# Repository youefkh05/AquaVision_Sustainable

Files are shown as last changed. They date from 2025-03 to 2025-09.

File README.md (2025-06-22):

# Lake Sensing Project

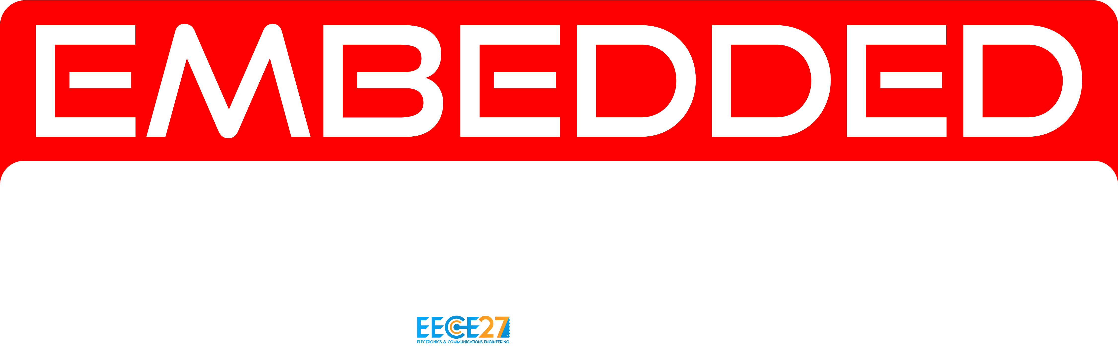
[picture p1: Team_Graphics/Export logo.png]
TEAM Logo Main


>[!IMPORTANT]
> This project is done as part of the Embedded Systems course [ELC2080] taught to second year Electronics and Elecrtic Communication Engineering Students at Cairo University Under the Supervision of Dr. Mohamed Riad.

### **[Dashboard Link](https://amirsameh1.github.io/test/)** To monitor project Data in real-time

## Brief Description

The system employs a dual-microcontroller setup to monitor and transmit water level data at two locations in a lake. The first module, positioned at the center where GSM signal is unavailable, measures water level and temperature, then relays the data via the ESP-NOW protocol to a second module stationed at the lake’s edge. This second unit consolidates the readings and transmits them to a base station using both GSM and Wi-Fi for broader connectivity.

## Project Features:

- Real Time Water-Level and temprature updates
- Accurate Data Measurments using different sensors
- Tracking measurements at two different locations
- Intiutive dashboard displaying data
- GSM connectivity
- Creative UI on Oled inspired by the Flipper Zero UI
- Alarm system if the Water Level is under a specified Limit

## Technical Highlights:

- Uses ESP32 Microcontroller for its wireless capability
- ESP-NOW Protocol used for communication between the two nodes
- GSM Connectivity Sends data to the dashboard in Real-Time.
- Overcoming GSM Challenges using an SMS system.
- Custom designed PCB for Each Node
    - Double Layer for Middle Node
    - Single Layer for Edge Node
- Power Supply filtering circuit to ensure safe operation of all components used
- Measuring water levels using two different methods
    - Ultrasonic Sensor
    - Time of Flight (ToF) Sensor
- Firbase used for storing and collecting data

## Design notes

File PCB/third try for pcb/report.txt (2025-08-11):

Plotted to 'C:\Users\Ziad\Desktop\sch\third try for pcb\gerber files\test-F_Cu.gbr'.
Plotted to 'C:\Users\Ziad\Desktop\sch\third try for pcb\gerber files\test-B_Cu.gbr'.
Plotted to 'C:\Users\Ziad\Desktop\sch\third try for pcb\gerber files\test-F_Paste.gbr'.
Plotted to 'C:\Users\Ziad\Desktop\sch\third try for pcb\gerber files\test-B_Paste.gbr'.
Plotted to 'C:\Users\Ziad\Desktop\sch\third try for pcb\gerber files\test-F_Silkscreen.gbr'.
Plotted to 'C:\Users\Ziad\Desktop\sch\third try for pcb\gerber files\test-B_Silkscreen.gbr'.
Plotted to 'C:\Users\Ziad\Desktop\sch\third try for pcb\gerber files\test-F_Mask.gbr'.
Plotted to 'C:\Users\Ziad\Desktop\sch\third try for pcb\gerber files\test-B_Mask.gbr'.
Plotted to 'C:\Users\Ziad\Desktop\sch\third try for pcb\gerber files\test-Edge_Cuts.gbr'.
Created Gerber job file 'C:\Users\Ziad\Desktop\sch\third try for pcb\gerber files\test-job.gbrjob'.
Info: Done.

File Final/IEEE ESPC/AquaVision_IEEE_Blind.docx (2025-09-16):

Implementation of an IoT-Based Sensor Network with AI Optimization for Aquaculture Systems

Abstract—This research introduces AquaVision, a smart aquaculture prototype integrating Internet of Things (IoT) and cloud technologies to improve fish farming in Egypt. The system continuously monitors key water parameters and automates corrective actions, reducing manual labor and errors. Real-time data analysis provides actionable insights for fish health and farm productivity. Experimental results confirm that AquaVision improves environmental stability and resource utilization. The prototype highlights a pathway toward sustainable, technology-driven aquaculture for food security and economic growth.

Keywords— IoT, aquaculture, smart farming, real-time monitoring, adaptive control, sustainable fish farming.

# I. Introduction

Egyptian aquaculture operations encounter major obstacles when handling water quality while optimizing resources and maintaining environmental equilibrium. Internet of Things technology enables fish farmers to solve their challenges through innovative solutions which transform traditional aquaculture operations. The research examines how IoT technology can be applied to Egyptian aquaculture through the development of AquaVision a prototype system which improves fish farm operations by providing automated monitoring capabilities.[1]

Recent studies show that IoT technology has great potential to enhance small-scale aquaponics systems through aquaculture automation. The combination of IoT technology enables reduced manual labor together with resource optimization and detailed water quality monitoring to create optimal conditions for fish and plants. Small-scale aquaculture operators encounter difficulties because they lack expertise in water chemistry and system maintenance while facing financial obstacles from expensive operational costs and power-hungry equipment.[1]

## A. CHALLANGES IN EGYPT’S AQUACULTURE SECTOR

The Egyptian aquaculture sector functions as an essential component of national food security together with economic development. Fish farmers face multiple problems because of water contamination together with inefficient resource management and environmental problems that stem from climate change. Traditional methods of aquaculture depend entirely on human monitoring which both requires extensive labor and results in frequent errors. The increasing prices of energy together with feed costs create significant financial pressure on fish farms that operate at small and medium scales.[1]

The proper maintenance of water conditions stands as a primary concern in aquaculture because temperature and pH level variations and dissolved oxygen changes result in decreased fish growth as well as increased death rates. Improper disposal of fish waste along with excess feed creates water pollution that affects both the farm site and nearby aquatic ecosystems as shown in fig 1[3]. The solution to these problems requires an automated system which can perform continuous monitoring and control of essential parameters.

Fig. 1. Challenges in aquaculture systems.

## B. The Role of IoT and AI in Smart Aquaculture

The Internet of Things technology offers fish farmers a solution to their operational challenges which includes water quality management and resource optimization and environmental sustainability through its integration into aquaculture operations. IoT-based systems enable real-time data collection and automated responses to environmental changes, as demonstrated in Fig 2. Smart feeders along with water quality sensors and automated aeration systems operate to maintain optimal conditions which eliminates the need for constant human monitoring.[2]

Fig. 2. Smart Aquaculture System.

# II. LITERATURE REVIEW

The implementation of IoT technology within aquaculture represents a forward-looking solution which addresses the problems of fish farmers especially in developing nations such as Egypt. Research demonstrates that implementing IoT-based systems within fish farms generates better productivity together with scalability and sustainability. According to a systematic review[2] IoT shows great potential to enhance both operational efficiency and financial returns in small-scale aquaponics systems which combine fish farming with hydroponics. The authors highlight IoT's vital role in resource optimization and constant water quality tracking and maintaining ideal conditions for fish and plant growth. Research has proven that smart monitoring and management systems based on IoT deliver improved business development alongside increased productivity to fish farming operations which utilize next-generation technologies.

## A. IoT in Aquaculture: Enhancing Monitoring and Environmental Control

The achievement of aquaculture systems depends heavily on maintaining high water quality. Multiple research investigations have proven that IoT-based monitoring provides benefits for maximizing environmental condition optimization.

- A systematic review shows how IoT brings value to small-scale aquaponics through resource optimization and detailed water quality monitoring of pH and dissolved oxygen and temperature and ammonia levels.[3]
- The research "Enhancing Tilapia Fish Farming Through IoT-driven Monitoring and Automatic Feeding Technology" presents real-time data collection evidence which demonstrates automated monitoring produces enhanced fish growth rates and better farm efficiency through cloud-based analytics.[4]

These Research shows that IoT technology-based real-time monitoring helps fish farmers achieve optimal conditions while lowering environmental threats and reducing the number of fish deaths.

## B. Automation in Fish Farming: Smart Feeding and Resource Optimization

Automated feeding systems function as a fundamental element for IoT-based fish farming operations because they solve problems caused by manual feeding processes.

- The "Improving Fish Quality and Yield: An Automated Monitoring System for Intensive Aquaculture." presents an IoT-based feeding solution which maximizes feeding times to prevent excessive feeding and feed loss.[6]
- The "Design of Automated Fish Feeder Using IoT" highlights how adjustable feeding patterns together with remote management and optimized portions lead to better fish health outcomes and higher farm efficiency.[7]

These Research shows that automated feed management based on IoT technology delivers higher operational efficiency together with decreased human mistakes and reduced operational expenses in fish farming operations.

## C. IoT-Driven Management Strategies and Business Development

The Internet of Things (IoT) technology assists farm operators by enhancing their ability to make decisions and manage their operations together with its monitoring and feeding capabilities.

- The “IoT-Based Smart Monitoring and Management System for Fish Farming,” describes how computer and communication technology enables operators to remotely supervise and control their fish farms.[8]
- A case study at the University of Rwanda Fish Farming and Research Station (UR-FFRs) shows that real-time alerts combined with cloud computing improve data analysis and decision-making through IoT implementation.[9].

These studies indicate that IoT implementation stands as a transformative force for aquaculture because it allows precise farming methods and boosts productivity and promotes sustainable business growth.

## D. Summary of Literature Findings

The examined studies reveal these crucial points which represent the main findings:

1. The use of real-time environmental parameter monitoring enables fish mortality reduction alongside improved resource utilization. Automated feeding systems enhance operational efficiency by stopping excess feeding which lowers feed waste and supports better fish development. IoT-based management approaches lead to improved decision-making and lower operational expenses and advance sustainable aquaculture operations.
2. The collected knowledge forms an essential base for creating AquaVision which will function as a smart aquaculture prototype to connect IoT systems for improved fish farm efficiency through automated operations and immediate monitoring.

# III. METHODOLOGY

## A. Sensor Data Collection

Our monitoring system employs multiple sensors for water quality and environmental conditions detection in aquaculture systems which track essential parameters. These parameters include:

- Water Level measures available water quantity for fish survival together with optimal growth conditions.
- The pH Level system tracks aquatic acidity levels which directly influences fish metabolic processes and their wellness.
- The temperature value (Temp) directly influences fish growth speed together with metabolic processes and dissolved oxygen capacity. Our system defines T &gt; 32°C as an initial critical threshold for temperature measurement.
- The dissolved oxygen level (DO) is necessary for aquatic life respiration and total water health with DO 8 mg/L as its standard critical threshold.
- Sunlight intensity determines the rate of photosynthesis among aquatic plants and algae which subsequently modifies oxygen production and nutrient cycling.

## B. System Components in Egyptian Fish Farms

The proposed system combines multiple essential elements to optimize fish farming operations in Egypt as shown in fig 3[2]. The aquatic tanks function as the main habitat for cultured fish while the water filtration system operates to preserve water quality through removal of debris and oxygen level management. The pipeline system enables water to move efficiently between fish tanks and filtration units. The system integrates plant cultivation to enable aquaponic practices which use fish waste as a natural fertilizer for plant growth. The system controls lighting to support both fish and plant growth and uses a water pump to control fluid movement and maintain system stability. The system achieves sustainable fish farming through the integrated operation of its components.

Fig. 3. The Overall Aquaponic System

## C. Prototype Development

The proposed system combines multiple essential elements to optimize fish farming operations in Egypt as shown in fig 4

Fig. 4. Prototype PCB with ESP32

The aquatic tanks function as the main habitat for cultured fish while the water filtration system operates to preserve water quality through removal of debris and oxygen level management. The pipeline system enables water to move efficiently between fish tanks and filtration units. The system integrates plant cultivation to enable aquaponic practices which use fish waste as a natural fertilizer for plant growth. The system controls lighting to support both fish and plant growth and uses a water pump to control fluid movement and maintain system stability. The system achieves sustainable fish farming through the integrated operation of its components.

For real-time control and monitoring of this process, two ESP32 microcontrollers are utilized. The first ESP32 is utilized for sensor parameter detection data acquisition such as water temperature, pH, and oxygen level. The second ESP32 is utilized for control and communication such as data uploading to a cloud server and downloading a remote smart phone application control command. This setup of two microcontrollers allows for real-time remote control and secure data acquisition, which permits users to make the correct decision and act on any irregularity in the aquaculture condition in real time.[10]

1) Algorithm for System Monitoring: The system employs a pre-programmed algorithm which takes sensor readings as an input and triggers the required action based on pre-programmed threshold values. The algorithm keeps on monitoring real-time sensor readings and makes required modifications to the control system.[2]

The algorithm operates as follows:

1. Read Sensor Data – It takes input from temperature, pH, DO, water level, and sunlight sensors.
2. Threshold Comparison – Compares values rising or falling below set thresholds (e.g, Temp > 32°C, DO > 8 mg/L).
3. Triggers Control Actions – Upon a parameter reaching its critical value, control actions such as the start of operation of aerators, water pumps, or shading systems are initiated.
4. Data Log and Alert System – Stores all the readings to be analyzed and sends alerts in the event of anomalies.

## D. Adaptive AI-Based Optimization

We use basic threshold-based control systems, but our extension introduces an AI-based adaptive control to dynamically adjust threshold levels based on environment conditions and trend histories. It operates as follows:

- The AI model analyzes past sensor readings for correlations and trends.
- Instead of using constant limits (e.g., Temp > 32°C, DO > 8 mg/L), the AI adjusts them based on external inputs such as weather outlooks, phases of fish growth, and seasons.
- This optimization maximizes water quality, reduces energy consumption, and improves fish health by keeping the parameters within an optimal range rather than fixed pre-set values.

# IV. EXPERIMENTAL RESULTS

The AquaVision prototype was evaluated under small-scale aquarium conditions due to limitations in accessing a commercial fish farm. Despite this constraint, the setup provided a controlled environment to validate the system’s functionality in monitoring water parameters such as temperature and water level.[10]

As shown in fig 5, The AquaVision prototype was evaluated under small-scale aquarium conditions due to limitations in accessing a commercial fish farm. Despite this constraint, the setup provided a controlled environment to validate the system’s functionality in monitoring water parameters such as temperature and water level.[10]

Previous studies report that manual monitoring in aquaculture achieves only around 30% accuracy in maintaining optimal water parameters due to delays, inconsistency, and human error [6]. In contrast, our prototype, although still at an early stage, achieved an accuracy of approximately 40% when compared against calibrated sensors and expected threshold behavior.

While this result indicates that AquaVision has not yet reached its full potential, it demonstrates a clear improvement over traditional manual methods. The accuracy is expected to increase significantly as the AI-based adaptive control algorithm is further trained and optimized with more environmental data from larger-scale fish farm deployments.

Fig. 5. Manual vs our AI prototype accuracy

# V. CONCLUSION

Application of IoT technology to Egypt's aquaculture industry is a new idea of water quality management, being environment conserving, and an environmental guardian. The process here demonstrates the worth of real-time monitoring, automated control, and machine learning analysis in fish farm productivity, enhancement of fish health, and cost reduction. The AquaVision demonstrator demonstrates the potential for sensor networks and cloud computing to work towards delivering data-driven decision-making, ideal farming conditions with maximum possible resource utilization.

Despite advancements, large application of IoT in aquaculture is constrained by the demands of start-up capital-expenditure investment, cyberattacks, and technical expertise. It will increase use of the technology in solving the above challenges through cost-saving methods, enhanced security mechanisms, and farmers' capacity building. Egypt's aquaculture fishery sector can increase productivity, sustainability, and profitability through the utilization of IoT, the path to a robust and evidence-based aquaculture

##### References

[1] M. A. H. bin Zamnuri, S. Qiu, M. A. A. bin Rizalmy, W. He, S. Yusoff, K. A. Roeroe, J. Du, and K.-H. Loh, “Integration of IoT in small-scale aquaponics to enhance efficiency and profitability: A systematic review,” Animals, vol. 14, no. 17, p. 2555, 2024.
[2] M. M. M. Mahmoud, R. Darwish, and A. M. Bassiuny, “Development of an economic smart aquaponic system based on IoT,” J. Eng. Res., vol. 12, no. 4, pp. 886–894, 2024.
[3] R. Basso-Sartori, “Current status of the microalgae application in agriculture and aquaculture,” unpublished, accessed Mar. 22, 2025.
[4] D. N. Purnamasari, I. R. Dhani, D. T. Laksono, M. Ulum, M. Hardiwansyah, and R. Alfita, “Enhancing tilapia fish farming through IoT-driven monitoring and automatic feeding technology,” in Proc. IEEE Int. Conf. Inf. Technol. Inf. Syst. (ITIS), Oct. 2023.
[5] M. Karim, M. Rahman, S. Alam, and T. Hasan, “IoT-based smart fish farming aquaculture monitoring system,” Apr. 2021.
[6] A. D. Kannan, R. Sivakumar, and P. Subramani, “Improving fish quality and yield: An automated monitoring system for intensive aquaculture,” Malays. J. Sci. Adv. Technol., 2024.
[7] P. Gade, M. Vaidya, D. Jaiswal, A. Titarmare, and R. Bambodkar, “Design of automated fish feeder using IoT,” Int. J. Res. Appl. Sci. Eng. Technol., vol. 11, no. 6, pp. 715–718, 2023.
[8] M. I. H. Bhuiyan, T. T. Mishuk, M. M. Islam, and M. S. Hossain, “IoT-based smart monitoring and management system for fish farming,” Bull. Electr. Eng. Informatics, vol. 11, no. 6, pp. 3183–3191, Dec. 2022. [Online].Available: https://journal.beei.org/index.php/EEI/article/view/3365
[9] M. I. H. Bhuiyan, T. T. Mishuk, M. M. Islam, and M. S. Hossain, “IoT-based smart monitoring and management system for fish farming,” Bull. Electr. Eng. Informatics, vol. 11, no. 6, pp. 3183–3191, Dec. 2022. [Online].Available: https://journal.beei.org/index.php/EEI/article/view/3365
[10] “AquaVision Sustainable,” GitHub repository, 2025. [Online].Available: https://tinyurl.com/3f9ve6mb

XXX-X-XXXX-XXXX-X/XX/$XX.00 ©20XX IEEE

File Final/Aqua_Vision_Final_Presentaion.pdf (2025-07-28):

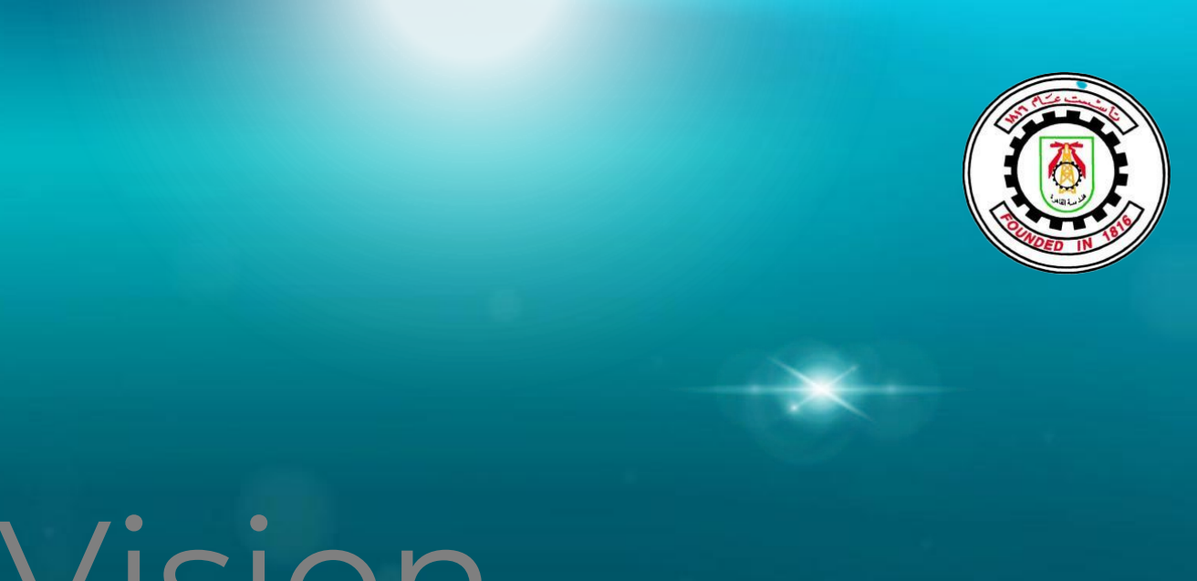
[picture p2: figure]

# Aqua Vision

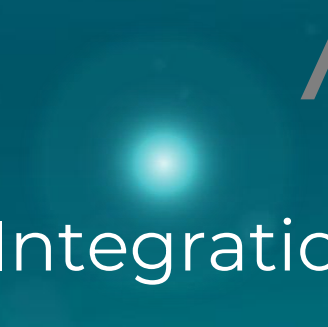
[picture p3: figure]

## Integration of IoT Technology with AI in Egypt's Aquaculture Industry

### Supervision: Dr. Samah El-Shafiey

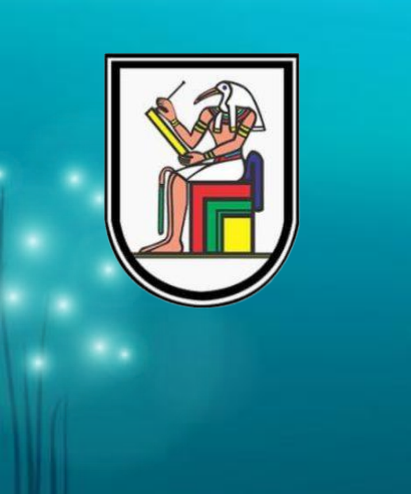
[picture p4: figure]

### Presented by: Yousef Khaled | Ameer Louly | Mohamed Ahmed

1

# TABLE OF CONTENTS

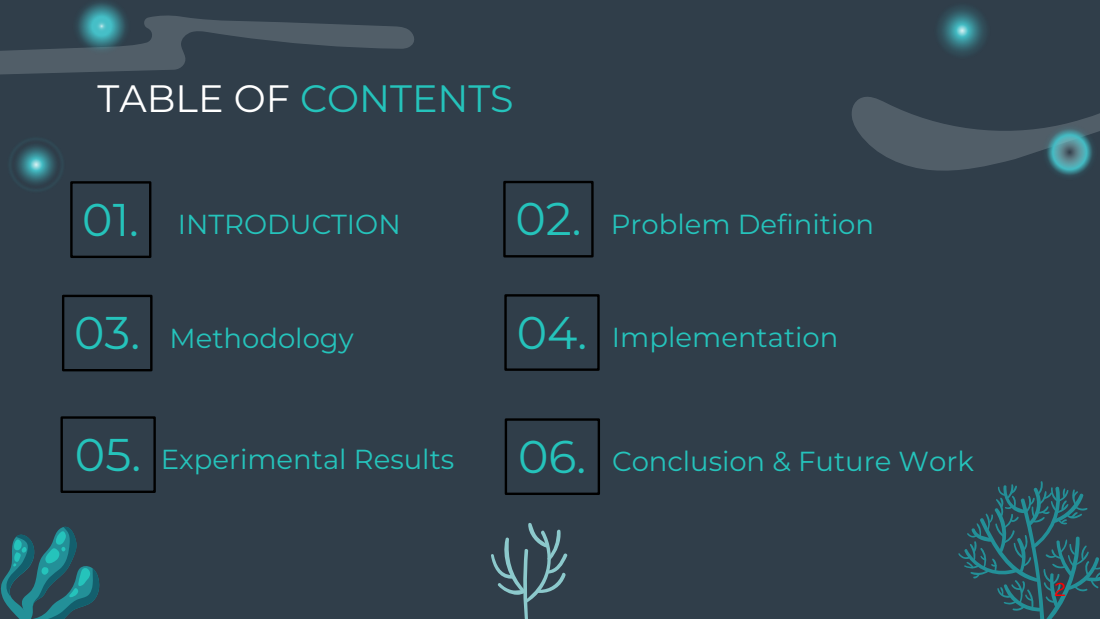
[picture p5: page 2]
INTRODUCTION; Problem Definition; Methodology; Implementation; Experimental Results; Conclusion & Future Work

# INTRODUCTION

01.

# 01. INTRODUCTION

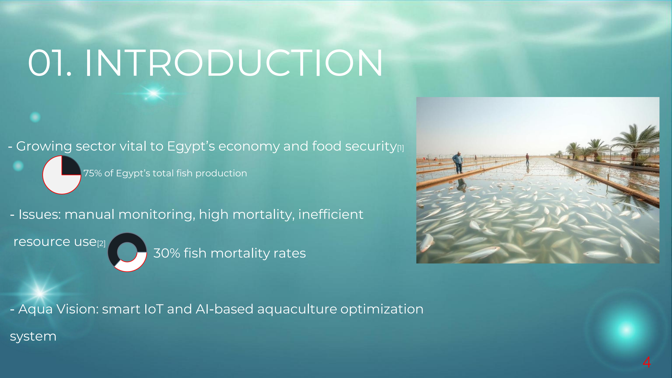
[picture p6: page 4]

- Growing sector vital to Egypt’s economy and food security[1]
- Issues: manual monitoring, high mortality, inefficient resource use[2]
- Aqua Vision: smart IoT and AI-based aquaculture optimization system

75% of Egypt’s total fish production

30% fish mortality rates

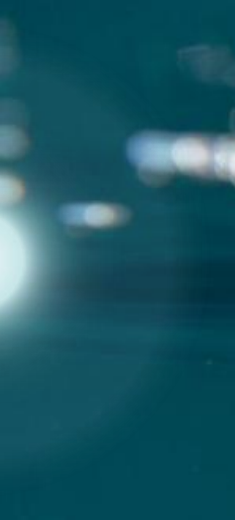
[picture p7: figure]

# Problem Definition

02.

# 02.Problem Definition

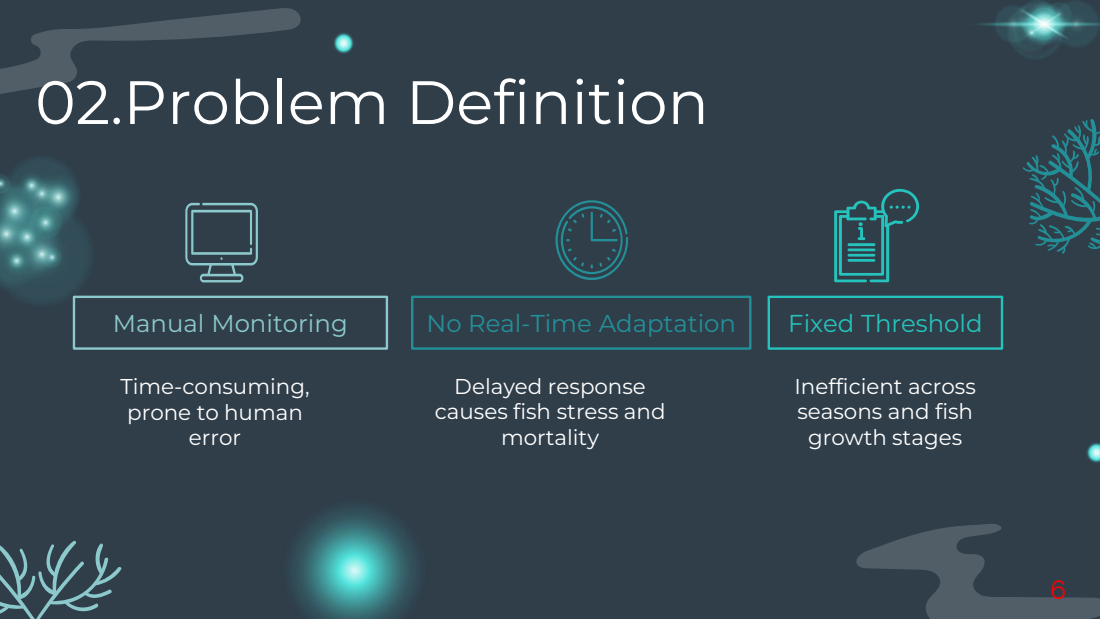
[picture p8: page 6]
Manual Monitoring; No Real-Time Adaptation; Fixed Threshold

Delayed response
causes fish stress and
mortality

Inefficient across
seasons and fish
growth stages

Time-consuming,
prone to human
error

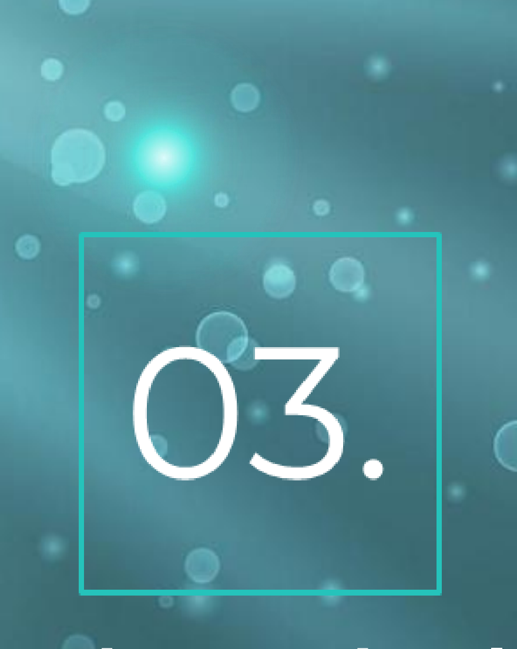
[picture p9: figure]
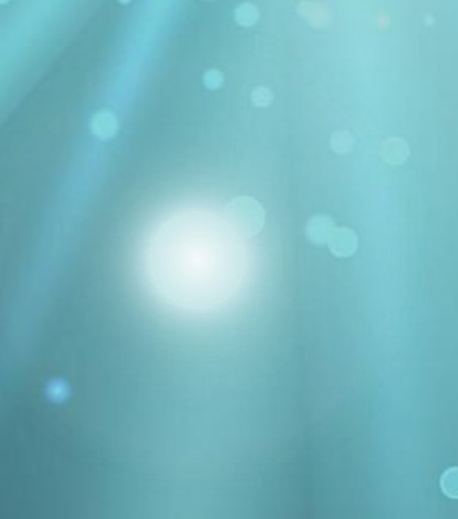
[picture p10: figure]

# Methodology

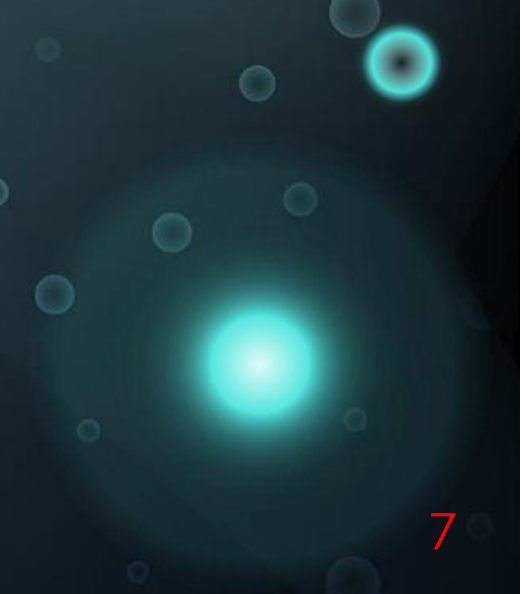
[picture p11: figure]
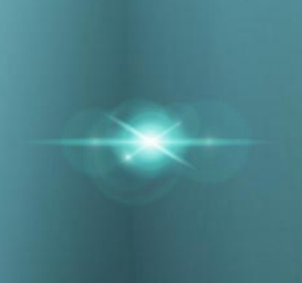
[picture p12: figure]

# Methodology

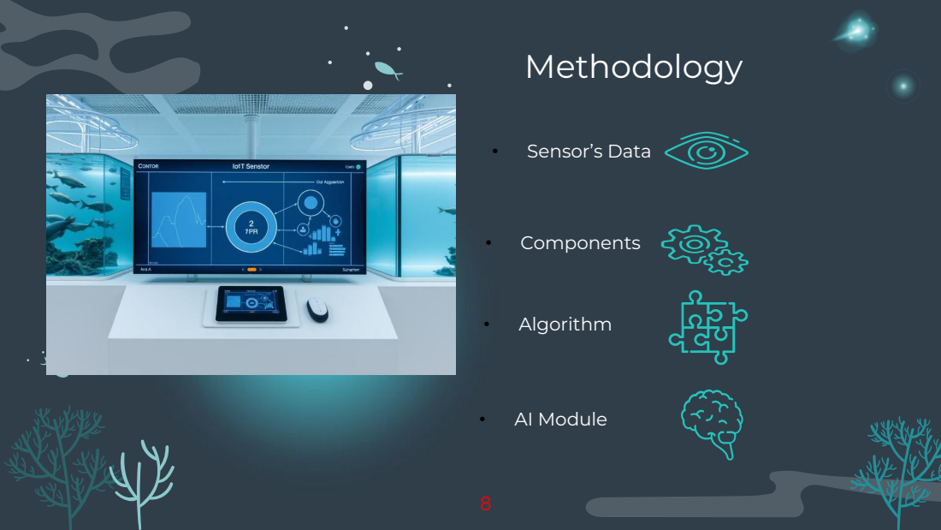
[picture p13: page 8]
• Sensor’s Data; • Components; • Algorithm; • AI Module

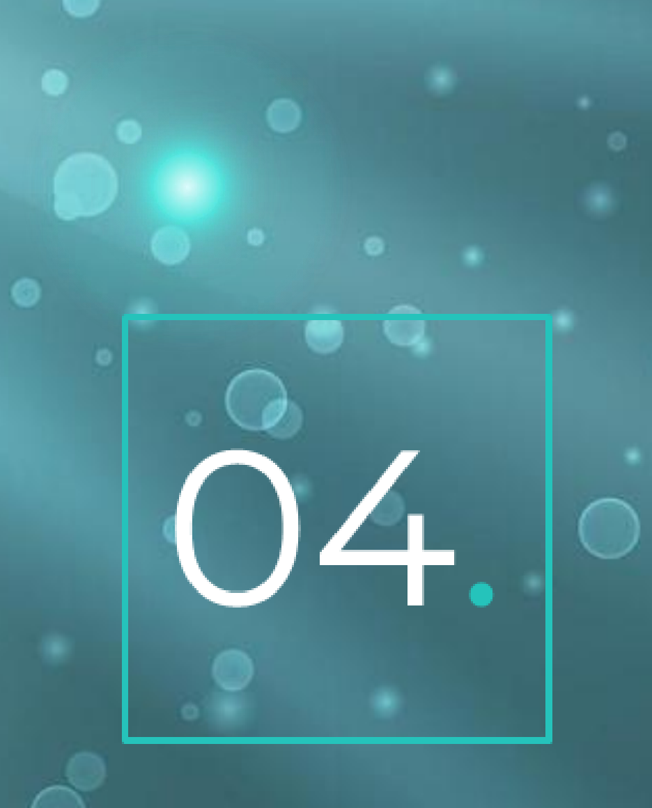
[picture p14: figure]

# Implementation

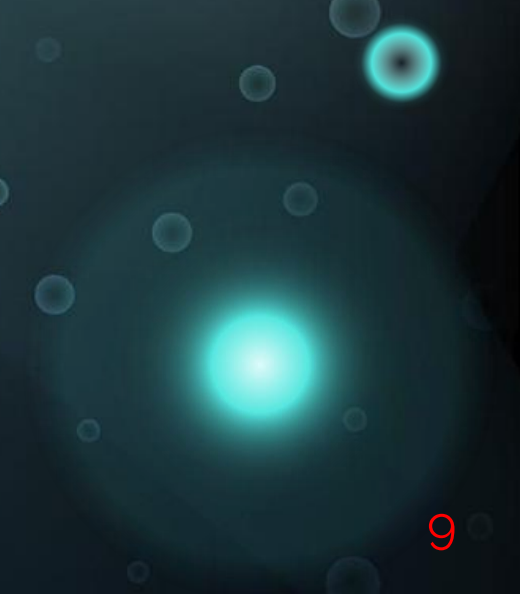
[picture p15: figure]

# Implementation

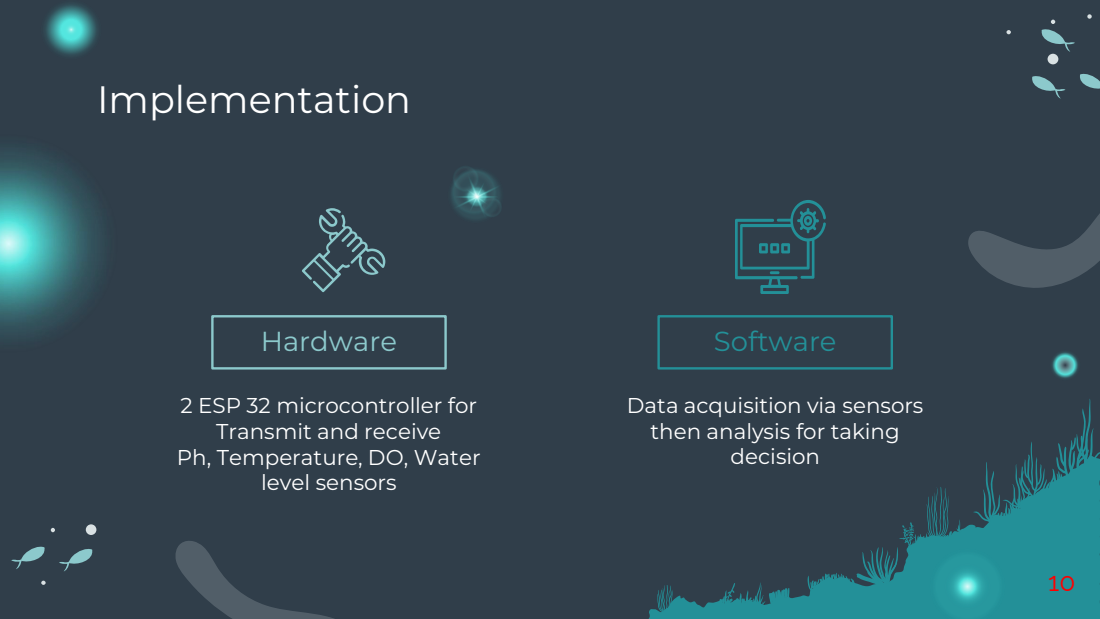
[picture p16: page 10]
Hardware; Software; level sensors; decision

2 ESP 32 microcontroller for
Transmit and receive
Ph, Temperature, DO, Water

Data acquisition via sensors
then analysis for taking

# Algorithm

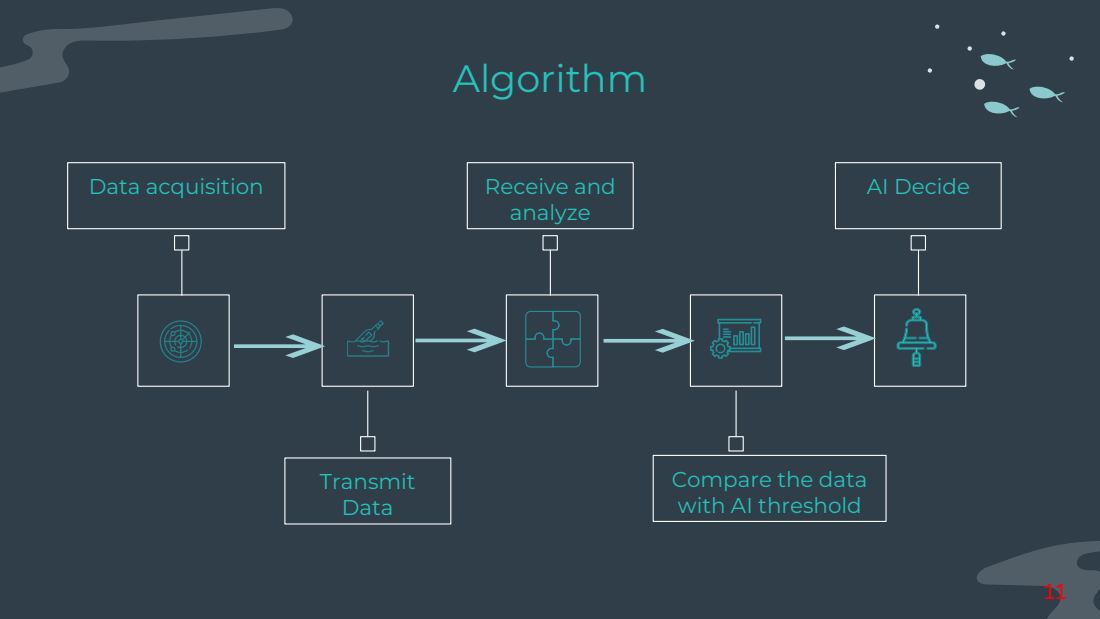
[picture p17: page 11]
Data acquisition; Receive and; analyze; AI Decide; Transmit Data

Compare the data
with AI threshold

# Experimental Results 5

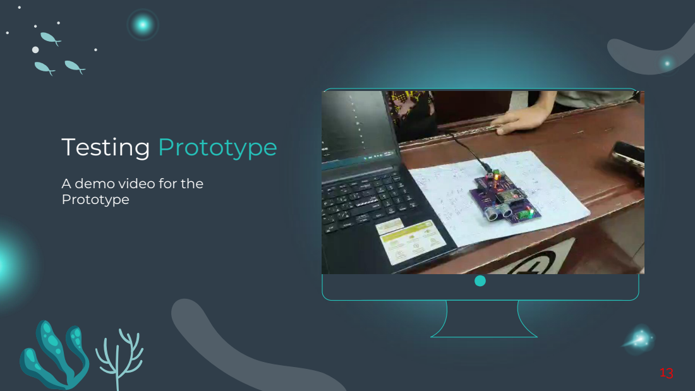
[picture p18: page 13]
Testing Prototype

A demo video for the
Prototype

# Key Results

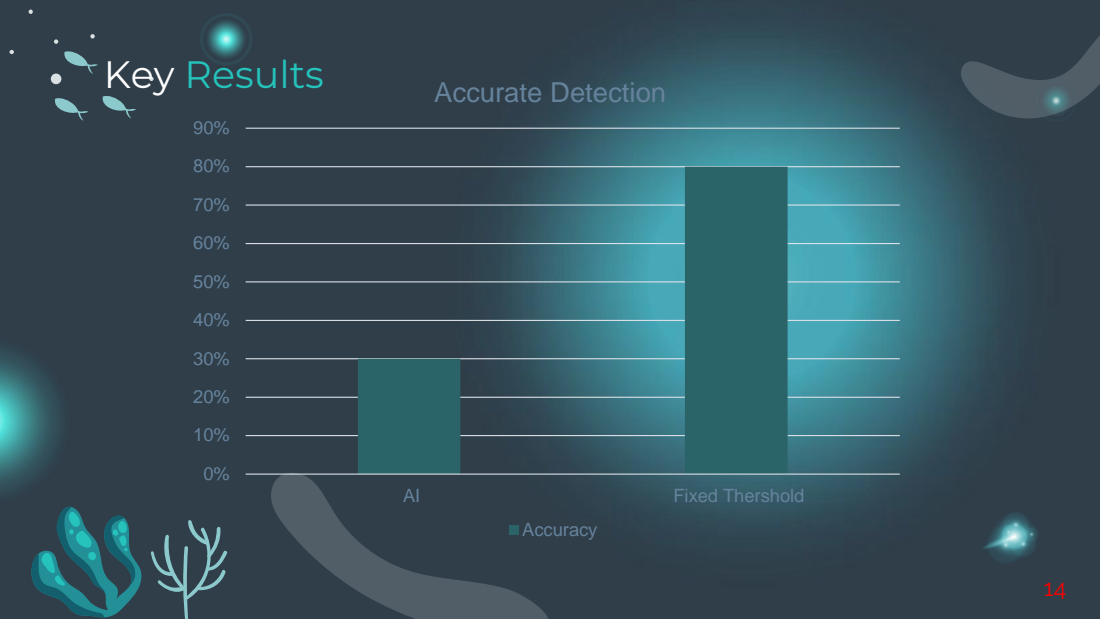
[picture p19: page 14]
Fixed Thershold; Accurate Detection; Accuracy

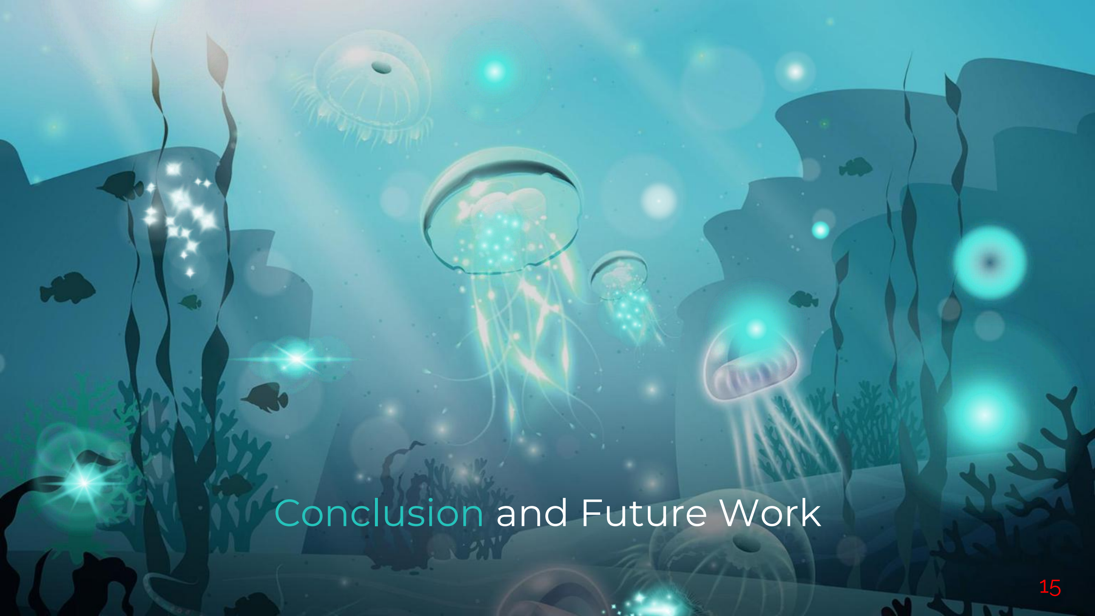
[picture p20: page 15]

# Conclusion and Future Work

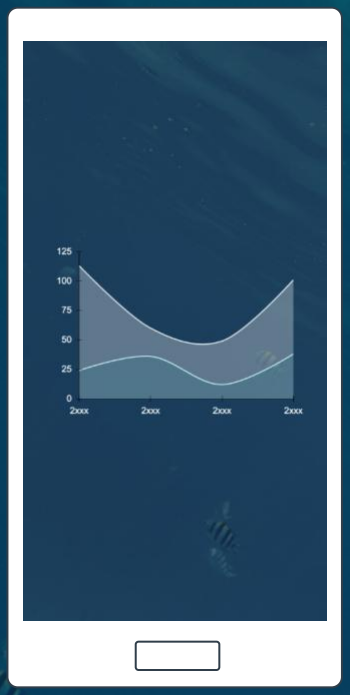
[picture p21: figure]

# Conclusion

- IoT and AI integration boosts smart aquaculture
- Enhances monitoring, cost efficiency, sustainability

## Cloud and mobile remote management

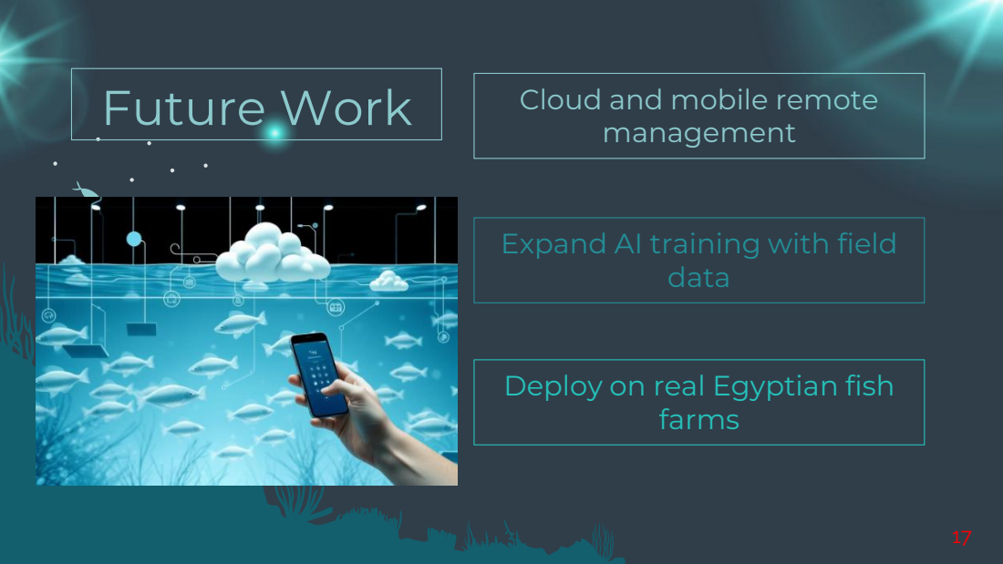
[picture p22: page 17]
data; farms; Future Work

Expand AI training with field

Deploy on real Egyptian fish

# THANKS!

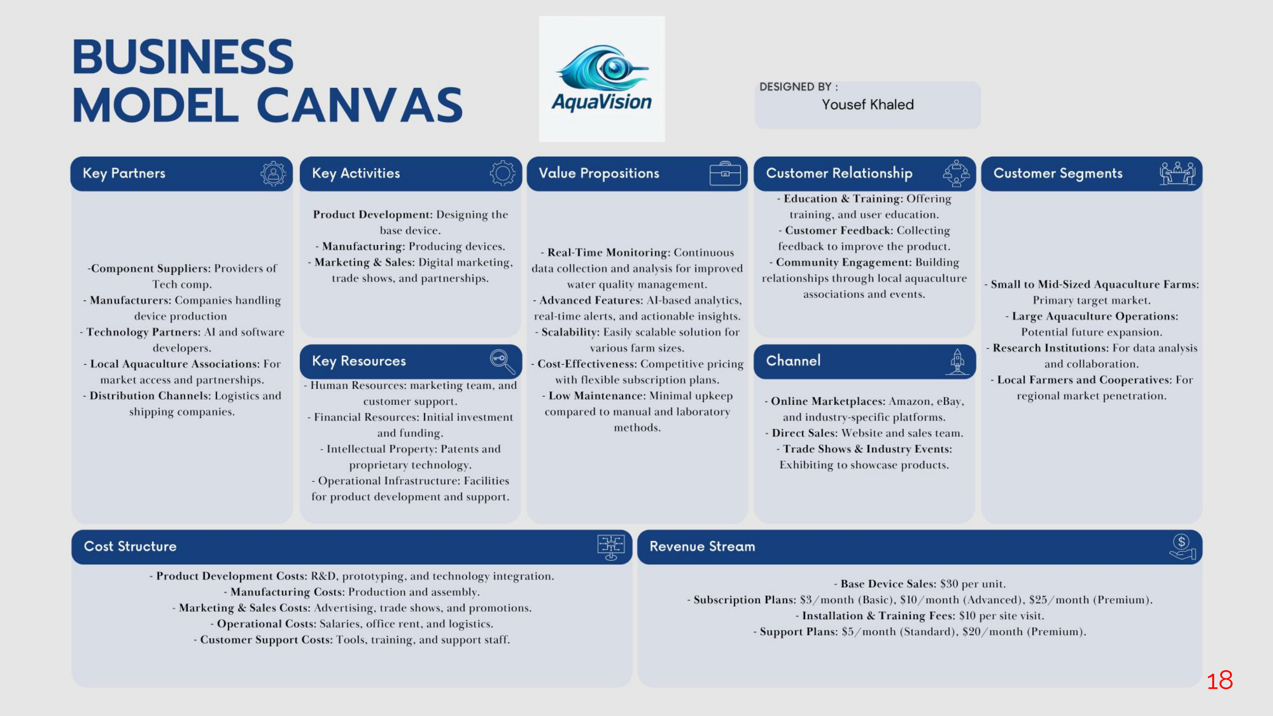
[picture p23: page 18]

CREDITS: This presentation template was created by Slidesgo, (http://bit.ly/2Tynxth) and includes icons by Flaticon, (http://bit.ly/2TyoMsr) and infographics & images by Freepik (http://bit.ly/2TtBDfr)

# Do you have any questions?

CREDITS: This presentation template was created by Slidesgo, (http://bit.ly/2Tynxth) and includes icons by Flaticon, (http://bit.ly/2TyoMsr) and infographics & images by Freepik (http://bit.ly/2TtBDfr)

# THANKS!

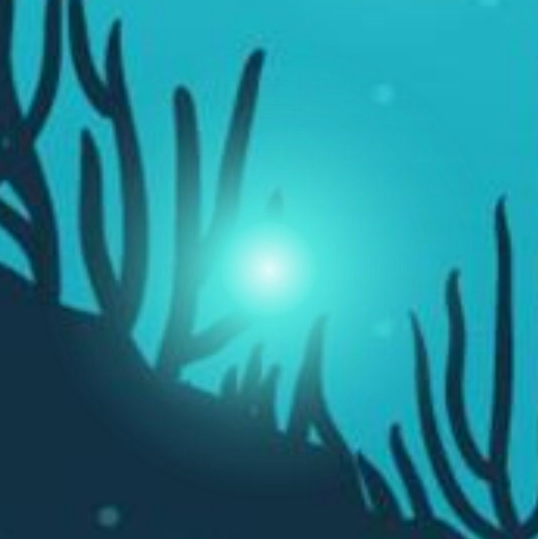
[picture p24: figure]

# Do you have any questions?

# QR Code

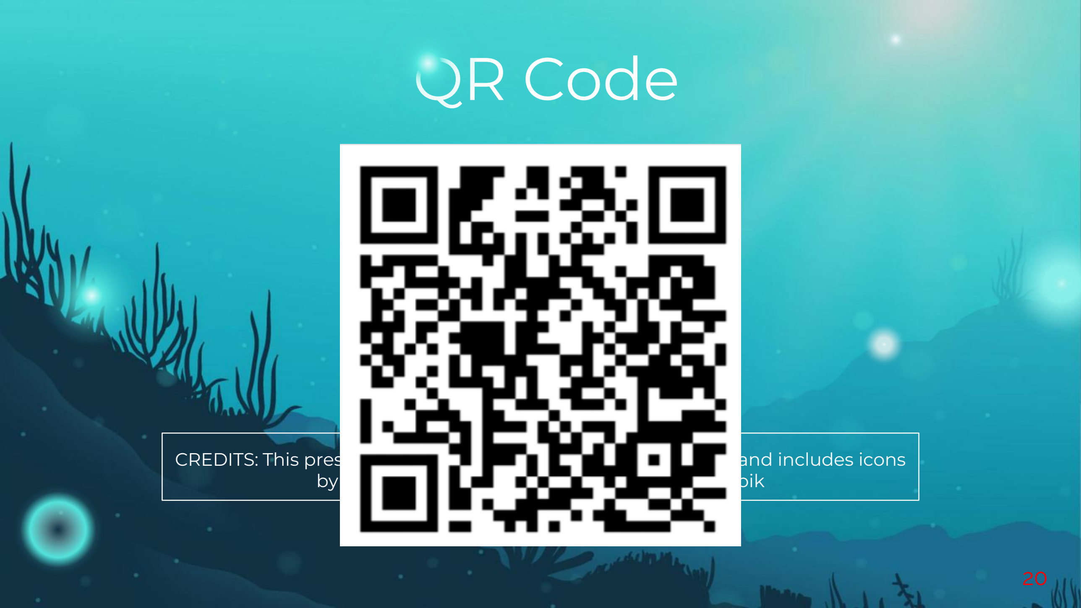
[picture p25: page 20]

CREDITS: This presentation template was created by Slidesgo, (http://bit.ly/2Tynxth) and includes icons by Flaticon, (http://bit.ly/2TyoMsr) and infographics & images by Freepik (http://bit.ly/2TtBDfr)

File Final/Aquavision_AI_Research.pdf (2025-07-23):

Cairo University

### | P a g e 1

## Integration of IoT Technology with AI in Egypt's Aquaculture Industry: AquaVision Prototype for Sustainable Fish Farming

Yousef Khaled Omar Mahmoud, Engineering, E-mail: yousef.mahmoud03@eng-st.cu.edu.eg

Gamaa Street, Giza, Egypt

Abstract

The aquaculture sector of Egypt encounters difficulties in managing water quality while optimizing resources and achieving sustainable operations. The research presents AquaVision which serves as an Internet of Things (IoT) based prototype to boost fish farm operational efficiency. The AquaVision system operates through real-time sensor data measurement which enables precise water parameter control that enhances fish growth while minimizing resource consumption. The system provides remote monitoring capabilities and control functions that help users make informed decisions and data analytics tools that generate valuable insights about farm productivity. the innovative system tackles fundamental issues while advancing sustainable aquaculture operations that operate in Egypt.

### 1 INTRODUCTION

Egyptian aquaculture operations encounter major obstacles when handling water quality while optimizing resources and maintaining environmental equilibrium. Internet of Things technology enables fish farmers to solve their challenges through innovative solutions which transform traditional aquaculture operations. The research examines how IoT technology can be applied to Egyptian aquaculture through the development of AquaVision a prototype system which improves fish farm operations by providing automated monitoring capabilities.[1]

Recent studies show that IoT technology has great potential to enhance small-scale aquaponics systems through aquaculture automation. The combination of IoT technology enables reduced manual labor together with resource optimization and detailed water quality monitoring to create optimal conditions for fish and plants. Small-scale aquaculture operators encounter difficulties because they lack expertise in water chemistry and system maintenance while facing financial obstacles from expensive operational costs and power-hungry equipment.[1]

The AquaVision prototype aims to address these challenges by leveraging IoT technology to automate and optimize various aspects of fish farming. The system incorporates real-time sensors to monitor water quality parameters, such as pH, dissolved oxygen, and temperature, and uses this data to adjust water circulation, aeration, and feeding schedules. This not only ensures optimal growing conditions for the fish but also helps to minimize water and energy consumption, thereby enhancing the environmental sustainability of the operation.

AquaVision combines IoT technology to give fish farm owners the capability to track and operate their operations from anywhere which helps them base their decisions on data and react to environmental changes. Through its analytics features the system delivers essential information about fish development patterns together with feeding behaviors and farm productivity which helps farmers enhance their operational efficiency and increase their profits.

AquaVision implementation within Egypt's aquaculture sector stands to solve the fundamental issues which affect fish farmers including water control and resource utilization along with environmental conservation.[2] This engineering prototype uses IoT technology to transform fish farming operations which will drive the aquaculture sector's overall growth and advancement throughout Egypt.

### 1.1 CHALLANGES IN EGYPT’S AQUACULTURE SECTOR

The Egyptian aquaculture sector functions as an essential component of national food security together with economic development. Fish farmers face multiple problems because of water contamination together with inefficient resource management and environmental problems that stem from climate change. Traditional methods of aquaculture depend entirely on human monitoring which both requires extensive labor and

### | P a g e 2

results in frequent errors. The increasing prices of energy together with feed costs create significant financial pressure on fish farms that operate at small and medium scales.[1]

The proper maintenance of water conditions stands as a primary concern in aquaculture because temperature and pH level variations and dissolved oxygen changes result in decreased fish growth as well as increased death rates. Improper disposal of fish waste along with excess feed creates water pollution that affects both the farm site and nearby aquatic ecosystems as shown in fig 1[3]. The solution to these problems requires an automated system which can perform continuous monitoring and control of essential parameters.


### 1.2 The Role of IoT and AI in Smart Aquaculture

The Internet of Things technology offers fish farmers a solution to their operational challenges which includes water quality management and resource optimization and environmental sustainability through its integration into aquaculture operations. IoT-based systems enable real-time data collection and automated responses to environmental changes, as demonstrated in Fig 2. Smart feeders along with water quality sensors and automated aeration systems operate to maintain optimal conditions which eliminates the need for constant human monitoring.[2]


Artificial Intelligence (AI) when integrated with IoT-based aquaculture systems enables improved decision-making through fish behavior pattern prediction and feeding schedule optimization and early warning system detection. Machine learning algorithms examine both historical and present data to provide recommendations which enhance fish growth performance and decrease waste production and better allocate resources. The adaptability of AI-based smart aquaculture systems towards environmental changes outperforms traditional systems which leads to better cost-effectiveness and enhanced resilience in the long term.

By integrating AI into IoT-based aquaculture systems, AquaVision aims to bridge the gap between traditional and modern fish farming methods. This research explores how a smart, automated system can transform Egypt’s aquaculture sector, making it more sustainable, profitable, and resilient to external challenges.

Fig 1 Challenges in aquaculture systems

Fig 2 Smart Aquaculture System

### | P a g e 3

### 2 LITERATURE REVIEW

The implementation of IoT technology within aquaculture represents a forward-looking solution which addresses the problems of fish farmers especially in developing nations such as Egypt. Research demonstrates that implementing IoT-based systems within fish farms generates better productivity together with scalability and sustainability. According to a systematic review[2] IoT shows great potential to enhance both operational efficiency and financial returns in small-scale aquaponics systems which combine fish farming with hydroponics. The authors highlight IoT's vital role in resource optimization and constant water quality tracking and maintaining ideal conditions for fish and plant growth. Research has proven that smart monitoring and management systems based on IoT deliver improved business development alongside increased productivity to fish farming operations which utilize next-generation technologies.

### 2.1 IoT in Aquaculture: Enhancing Monitoring and Environmental Control

The achievement of aquaculture systems depends heavily on maintaining high water quality. Multiple research investigations have proven that IoT-based monitoring provides benefits for maximizing environmental condition optimization.

- A systematic review shows how IoT brings value to small-scale aquaponics through resource optimization and detailed water quality monitoring of pH and dissolved oxygen and temperature and ammonia levels.[3]
- The research "Enhancing Tilapia Fish Farming Through IoT-driven Monitoring and Automatic Feeding Technology" presents real-time data collection evidence which demonstrates automated monitoring produces enhanced fish growth rates and better farm efficiency through cloud-based analytics.[4]

These Research shows that IoT technology-based real-time monitoring helps fish farmers achieve optimal conditions while lowering environmental threats and reducing the number of fish deaths..

### 2.2 Automation in Fish Farming: Smart Feeding and Resource Optimization

Automated feeding systems function as a fundamental element for IoT-based fish farming operations because they solve problems caused by manual feeding processes.

- The "Improving Fish Quality and Yield: An Automated Monitoring System for Intensive Aquaculture." presents an IoT-based feeding solution which maximizes feeding times to prevent excessive feeding and feed loss.[6]
- The "Design of Automated Fish Feeder Using IoT" highlights how adjustable feeding patterns together with remote management and optimized portions lead to better fish health outcomes and higher farm efficiency[7].

These Research shows that automated feed management based on IoT technology delivers higher operational efficiency together with decreased human mistakes and reduced operational expenses in fish farming operations.

### 2.3 IoT-Driven Management Strategies and Business Development

The Internet of Things (IoT) technology assists farm operators by enhancing their ability to make decisions and manage their operations together with its monitoring and feeding capabilities.

- The “IoT-Based Smart Monitoring and Management System for Fish Farming,” describes how computer and communication technology enables operators to remotely supervise and control their fish farms.[8]
- A case study at the University of Rwanda Fish Farming and Research Station (UR-FFRs) shows that real-time alerts combined with cloud computing improve data analysis and decision-making through IoT implementation[9].

### | P a g e 4

These studies indicate that IoT implementation stands as a transformative force for aquaculture because it allows precise farming methods and boosts productivity and promotes sustainable business growth.

### 2.4 Summary of Literature Findings

The examined studies reveal these crucial points which represent the main findings:

The use of real-time environmental parameter monitoring enables fish mortality reduction alongside improved resource utilization. Automated feeding systems enhance operational efficiency by stopping excess feeding which lowers feed waste and supports better fish development. IoT-based management approaches lead to improved decision-making and lower operational expenses and advance sustainable aquaculture operations.

The collected knowledge forms an essential base for creating AquaVision which will function as a smart aquaculture prototype to connect IoT systems for improved fish farm efficiency through automated operations and immediate monitoring.

### 3 METHODOLOGY

### 3.1 Sensor Data Collection

Our monitoring system employs multiple sensors for water quality and environmental conditions detection in aquaculture systems which track essential parameters. These parameters include:

- Water Level measures available water quantity for fish survival together with optimal growth conditions.
- The pH Level system tracks aquatic acidity levels which directly influences fish metabolic processes and their wellness.
- The temperature value (T) directly influences fish growth speed together with metabolic processes and dissolved oxygen capacity. Our system defines T &gt; 32°C as an initial critical threshold for temperature measurement.
- The dissolved oxygen level (DO) is necessary for aquatic life respiration and total water health with DO & gt; 8 mg/L as its standard critical threshold.
- Sunlight intensity determines the rate of photosynthesis among aquatic plants and algae which subsequently modifies oxygen production and nutrient cycling.

### 3.2 System Components in Egyptian Fish Farms

The proposed system combines multiple essential elements to optimize fish farming operations in Egypt as shown in fig 3[2]. The aquatic tanks function as the main habitat for cultured fish while the water filtration system operates to preserve water quality through removal of debris and oxygen level management. The pipeline system enables water to move efficiently between fish tanks and filtration units. The system integrates plant cultivation to enable aquaponic practices which use fish waste as a natural fertilizer for plant growth. The system controls lighting to support both fish and plant growth and uses a water pump to control fluid movement and maintain system stability. The system achieves sustainable fish farming through the integrated operation of its components.


Fig 3 The Overall Aquaponic System

### | P a g e 5

### 3.3 Prototype Development

The proposed system combines multiple essential elements to optimize fish farming operations in Egypt as shown in fig 3:[2]


The aquatic tanks function as the main habitat for cultured fish while the water filtration system operates to preserve water quality through removal of debris and oxygen level management. The pipeline system enables water to move efficiently between fish tanks and filtration units. The system integrates plant cultivation to enable aquaponic practices which use fish waste as a natural fertilizer for plant growth. The system controls lighting to support both fish and plant growth and uses a water pump to control fluid movement and maintain system stability. The system achieves sustainable fish farming through the integrated operation of its components.

For real-time control and monitoring of this process, two ESP32 microcontrollers are utilized. The first ESP32 is utilized for sensor parameter detection data acquisition such as water temperature, pH, and oxygen level. The second ESP32 is utilized for control and communication such as data uploading to a cloud server and downloading a remote smart phone application control command. This setup of two microcontrollers allows for real-time remote control and secure data acquisition, which permits users to make the correct decision and act on any irregularity in the aquaculture condition in real time.

### Algorithm for System Monitoring

The system employs a pre-programmed algorithm which takes sensor readings as an input and triggers the required action based on pre-programmed threshold values. The algorithm, as presented in fig 5[2], keeps on monitoring real-time sensor readings and makes required modifications to the control system.

Figure4 Prototype PCB with ESP32


### | P a g e 6

Fig 5 Flow Chart for the System

The algorithm operates as follows:

1. Read Sensor Data – It takes input from temperature, pH, DO, water level, and sunlight sensors.
2. Threshold Comparison – Compares values rising or falling below set thresholds (e.g., T > 32°C, DO > 8 mg/L).
3. Triggers Control Actions – Upon a parameter reaching its critical value, control actions such as the start of operation of aerators, water pumps, or shading systems are initiated.
4. Data Log and Alert System – Stores all the readings to be analyzed and sends alerts in the event of anomalies.

### 3.4 Adaptive AI-Based Optimization

We use basic threshold-based control systems, but our extension introduces an AI-based adaptive control to dynamically adjust threshold levels based on environment conditions and trend histories.

- The AI model analyzes past sensor readings for correlations and trends.

### | P a g e 7

- Instead of using constant limits (e.g., T > 32°C, DO > 8 mg/L), the AI adjusts them based on external inputs such as weather outlooks, phases of fish growth, and seasons.
- This optimization maximizes water quality, reduces energy consumption, and improves fish health by keeping the parameters within an optimal range rather than fixed pre-set values.

CONCLUSION

Application of IoT technology to Egypt's aquaculture industry is a new idea of water quality management, being environment conserving, and an environmental guardian. The process here demonstrates the worth of real-time monitoring, automated control, and machine learning analysis in fish farm productivity, enhancement of fish health, and cost reduction. The AquaVision demonstrator demonstrates the potential for sensor networks and cloud computing to work towards delivering data-driven decision-making, ideal farming conditions with maximum possible resource utilization.

Despite advancements, large application of IoT in aquaculture is constrained by the demands of start-up capital-expenditure investment, cyberattacks, and technical expertise. It will increase use of the technology in solving the above challenges through cost-saving methods, enhanced security mechanisms, and farmers' capacity building. Egypt's aquaculture fishery sector can increase productivity, sustainability, and profitability through the utilization of IoT, the path to a robust and evidence-based aquaculture

ACKNOWLEDGEMENT

I also want to extend my sincerest thanks to Dr. Samah El-Shafiey for her valuable comments, suggestions, and constant facilitation in this research. Her experience and knowledge that date back for decades have played a very significant role in guiding this study. I am much indebted to her for guidance on boundary demarcation in research and for literature support that was instrumental in crafting the postulates of this study.

### | P a g e 8

REFERENCES

[1] M.A.H. bin Zamnuri, S. Qiu, M.A.A. bin Rizalmy, W. He, S. Yusoff, K.A. Roeroe, J. Du, and K.-H. Loh, "Integration of IoT in Small-Scale Aquaponics to Enhance Efficiency and Profitability: A Systematic Review," Animals, vol. 14, no. 17, pp. 2555, 2024.
[2] M.M.M. Mahmoud, R. Darwish, and A.M. Bassiuny, "Development of an Economic Smart Aquaponic System Based on IoT," Journal of Engineering Research, vol. 12, no. 4, pp. 886-894, 2024.
[3] R. Basso-Sartori, “Current status of the microalgae application in agriculture and aquaculture,” [accessed 22 Mar 2025].
[4] D. N. Purnamasari, I. R. Dhani, D. T. Laksono, M. Ulum, M. Hardiwansyah, and R. Alfita, "Enhancing Tilapia Fish Farming Through IoT-driven Monitoring and Automatic Feeding Technology," in Proceedings of the IEEE International Conference on Information Technology and Information Systems (ITIS), Oct. 2023.
[5] Karim et al, “IoT-Based Smart Fish Farming Aquaculture Monitoring System,” Apr. 2021.
[6] Kannan, Anne Dashini, et al. "Improving Fish Quality and Yield: An Automated Monitoring System for Intensive Aquaculture." Malaysian Journal of Science and Advanced Technology (2024).
[7] P. Gade, M. Vaidya, D. Jaiswal, A. Titarmare, and R. Bambodkar, "Design of Automated Fish Feeder Using IoT," International Journal for Research in Applied Science and Engineering Technology, vol. 11, no. 6, pp. 715–718, 2023.
[8] M. I. H. Bhuiyan, T. T. Mishuk, M. M. Islam, and M. S. Hossain, “IoT-Based Smart Monitoring and Management System for Fish Farming,” Bulletin of Electrical Engineering and Informatics, vol. 11, no. 6, pp. 3183–3191, Dec. 2022. [Online]. Available: https://journal.beei.org/index.php/EEI/article/view/3365.
[9] J. R. Mugisha, A. Ndagijimana, and C. Mugisha, “IoT Monitoring Systems in Fish Farming: Case Study of University of Rwanda Fish Farming and Research Station (UR-FFRs),” European Journal of Technology, vol. 6, no. 1, pp. 12–25, 2023. [Online]. Available: https://ajpojournals.org/journals/index.php/EJT/article/view/1559.

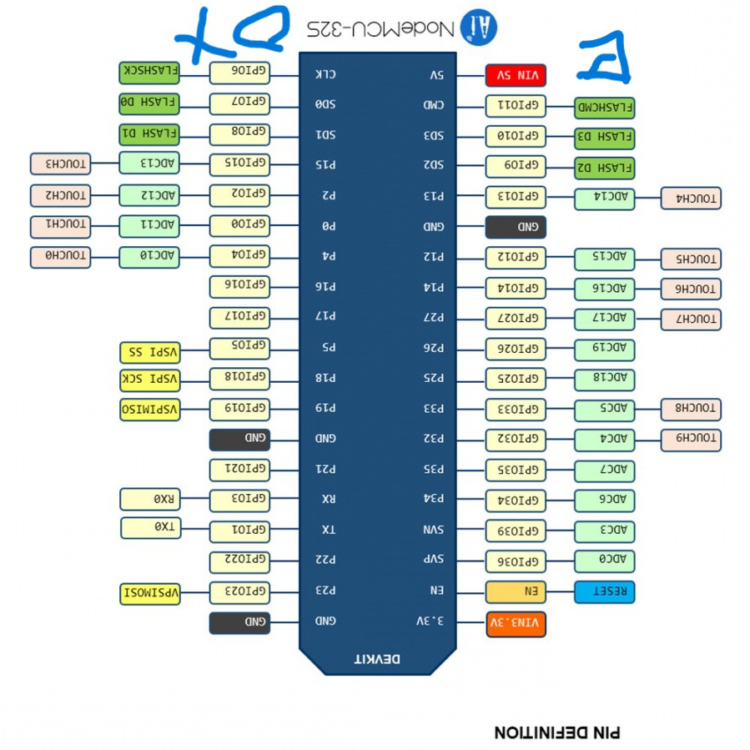
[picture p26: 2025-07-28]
Final/ESP32-Pinout.jpg

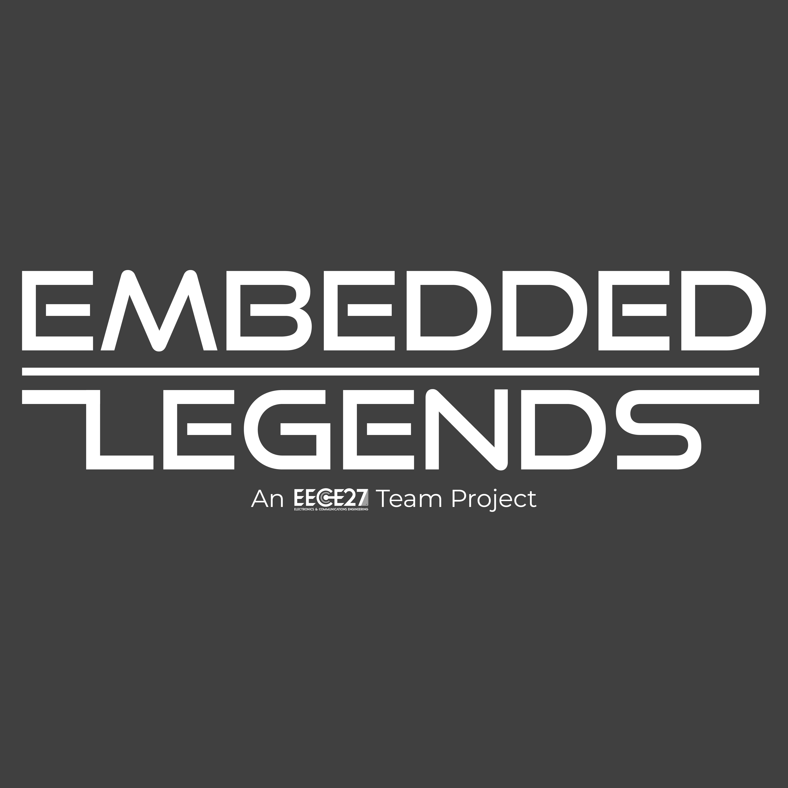
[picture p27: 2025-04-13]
Team_Graphics/Embedded legends-02.png

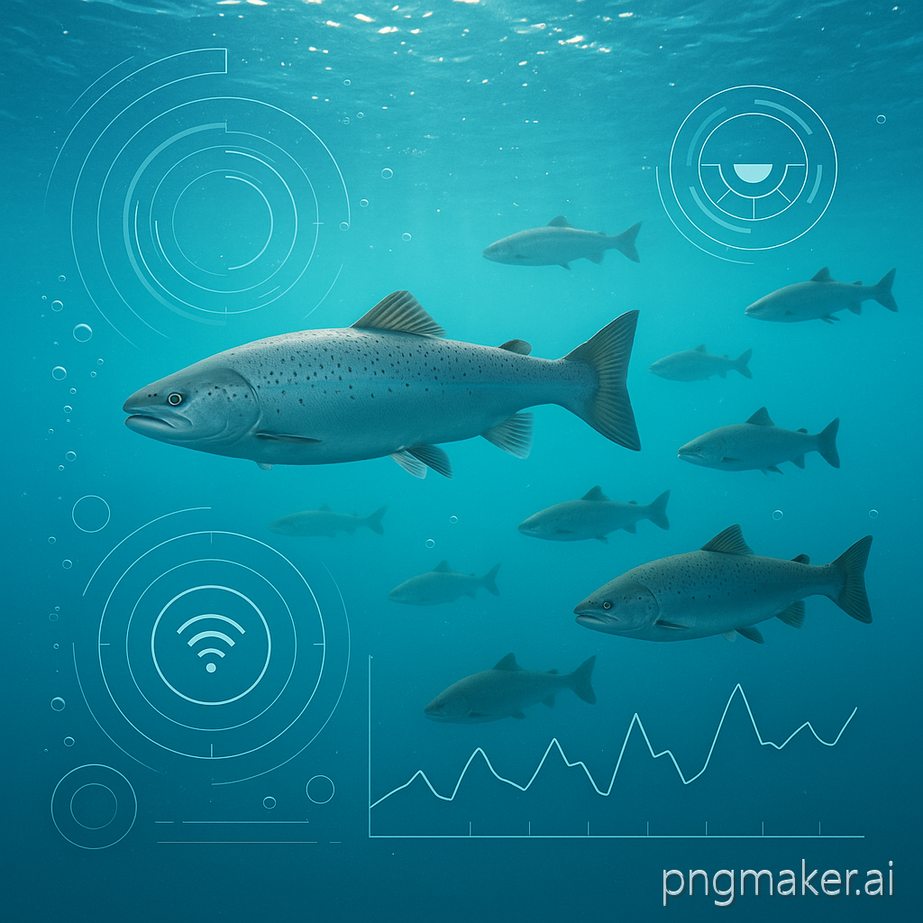
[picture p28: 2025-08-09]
AI/Source Code/AquaVision_resources/Fish_Sesnor.png

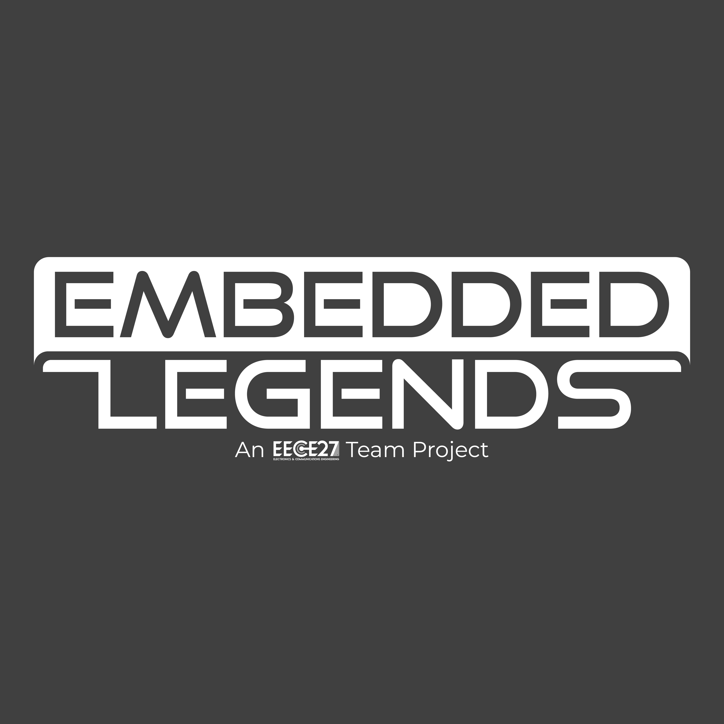
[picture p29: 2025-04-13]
Team_Graphics/Embedded legends-06.png

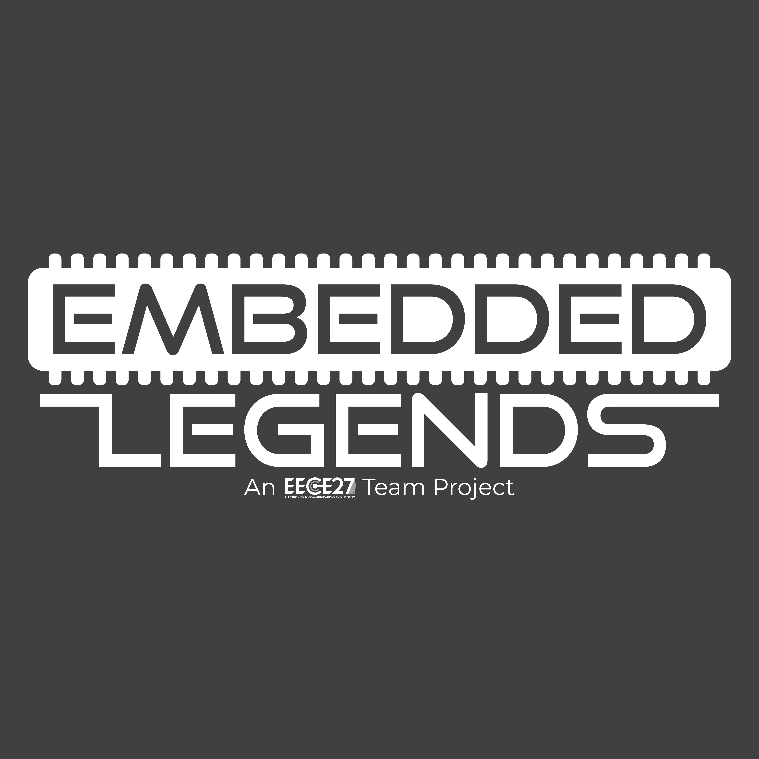
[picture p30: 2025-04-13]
Team_Graphics/Embedded legends-04.png

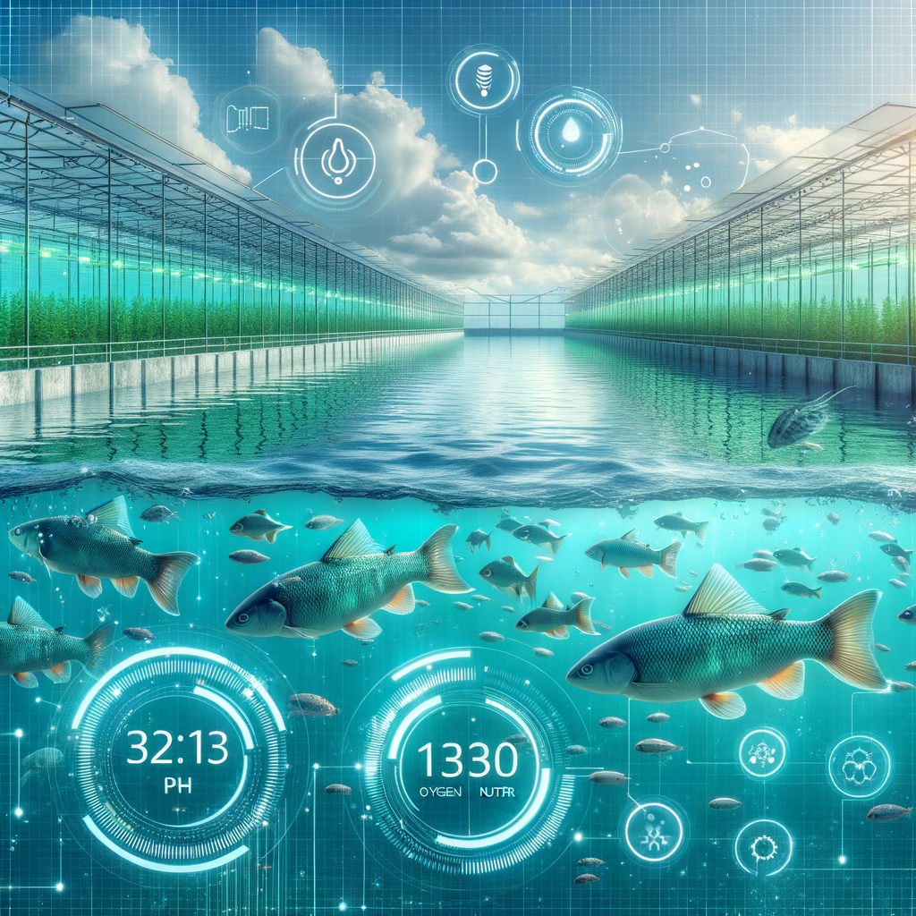
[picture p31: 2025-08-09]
AI/AquaVision_resources/Fish_Farm.png

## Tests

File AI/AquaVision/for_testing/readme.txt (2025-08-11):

AquaVision Executable

1. Prerequisites for Deployment 

Verify that version 9.10 (R2021a) of the MATLAB Runtime is installed.   
If not, you can run the MATLAB Runtime installer.
To find its location, enter
  
    >>mcrinstaller
      
at the MATLAB prompt.
NOTE: You will need administrator rights to run the MATLAB Runtime installer. 

Alternatively, download and install the Windows version of the MATLAB Runtime for R2021a 
from the following link on the MathWorks website:

    https://www.mathworks.com/products/compiler/mcr/index.html
   
For more information about the MATLAB Runtime and the MATLAB Runtime installer, see 
"Distribute Applications" in the MATLAB Compiler documentation  
in the MathWorks Documentation Center.

2. Files to Deploy and Package

Files to Package for Standalone 
================================
-AquaVision.exe
-MCRInstaller.exe 
    Note: if end users are unable to download the MATLAB Runtime using the
    instructions in the previous section, include it when building your 
    component by clicking the "Runtime included in package" link in the
    Deployment Tool.
-This readme file 

3. Definitions

For information on deployment terminology, go to
https://www.mathworks.com/help and select MATLAB Compiler >
Getting Started > About Application Deployment >
Deployment Product Terms in the MathWorks Documentation
Center.

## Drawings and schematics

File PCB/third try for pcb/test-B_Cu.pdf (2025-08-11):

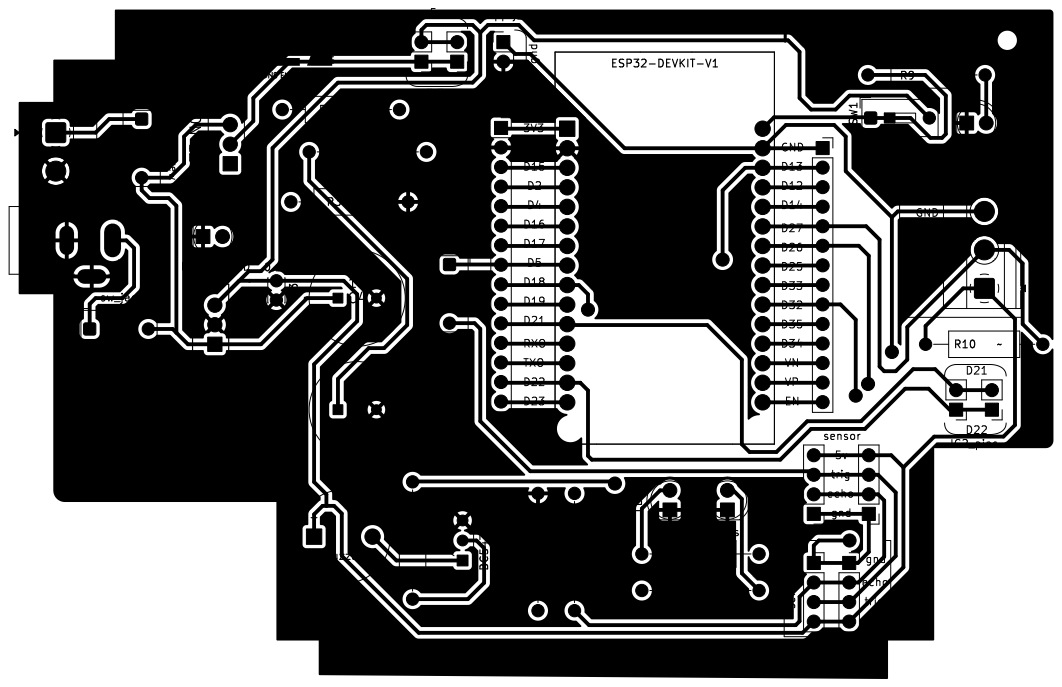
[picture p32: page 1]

Id: 2/9 Title: File: test.kicad_pcb Sheet: BACK-LAYER

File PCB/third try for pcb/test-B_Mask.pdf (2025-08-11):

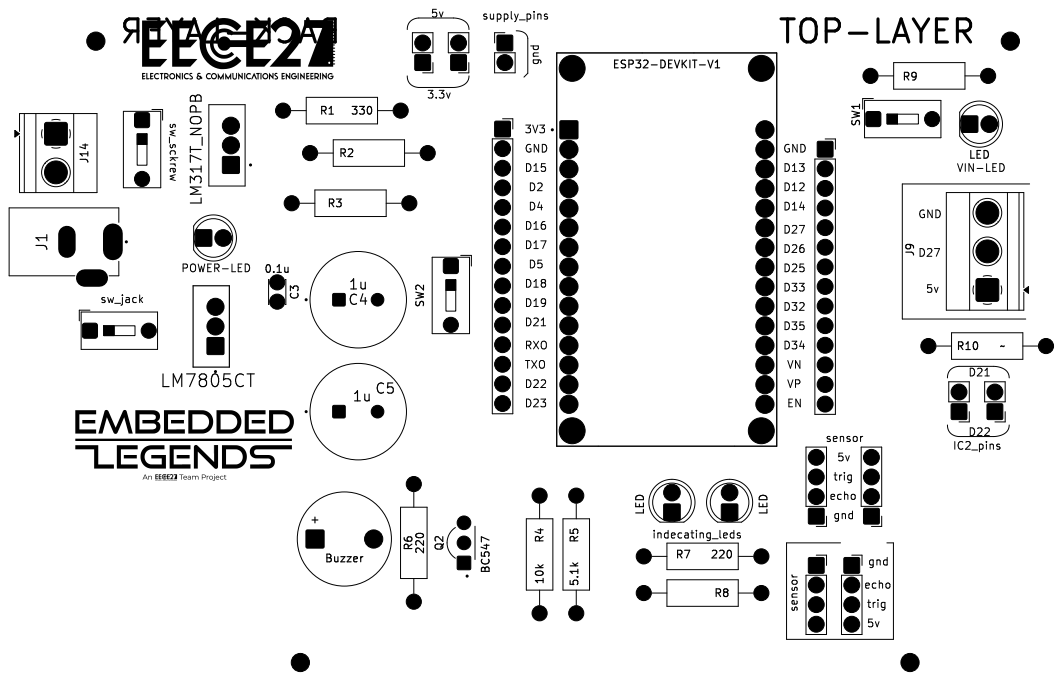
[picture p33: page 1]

Id: 8/9 Title: File: test.kicad_pcb Sheet: BACK-LAYER

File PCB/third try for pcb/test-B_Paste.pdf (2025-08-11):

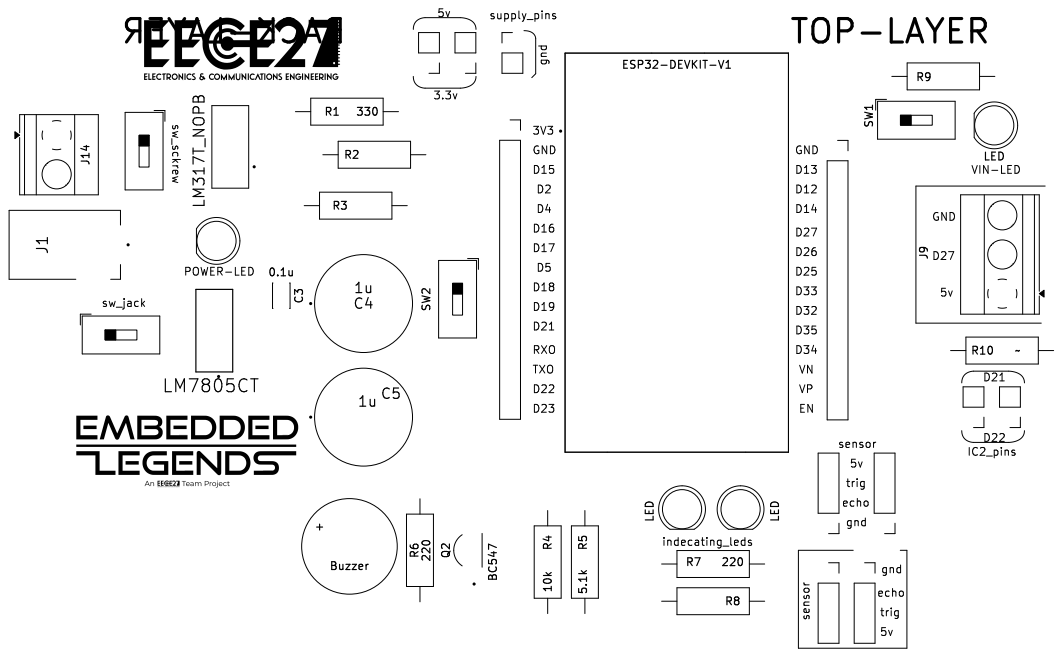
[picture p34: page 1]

Id: 4/9 Title: File: test.kicad_pcb Sheet: BACK-LAYER

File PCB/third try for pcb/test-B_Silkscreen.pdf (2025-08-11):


Id: 6/9 Title: File: test.kicad_pcb Sheet: BACK-LAYER

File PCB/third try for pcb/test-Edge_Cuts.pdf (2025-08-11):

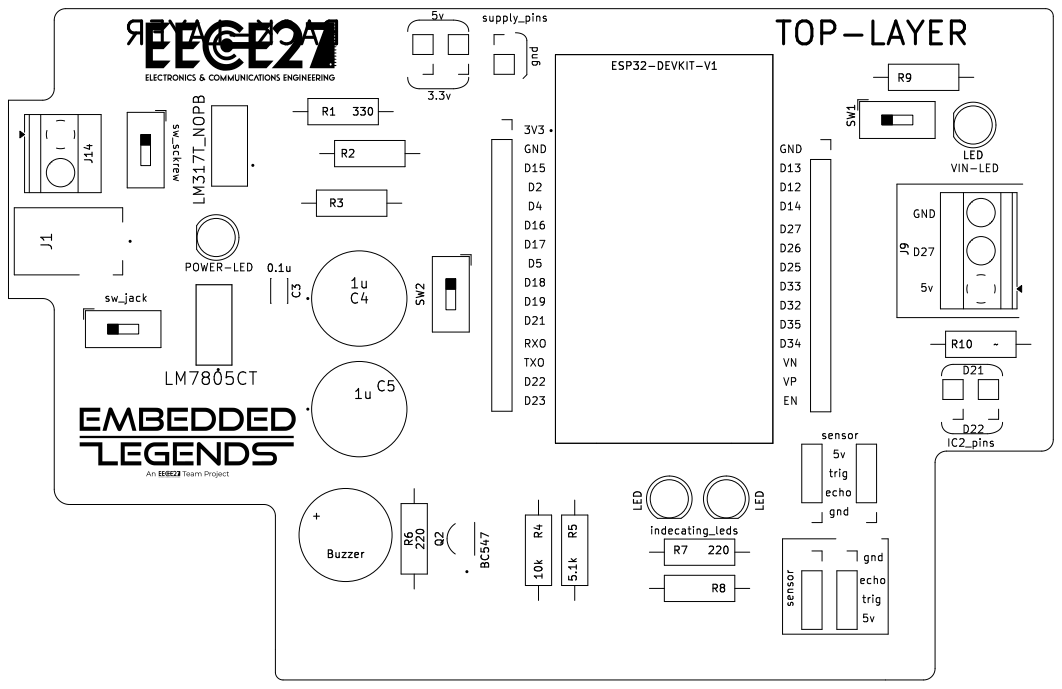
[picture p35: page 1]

Id: 9/9 Title: File: test.kicad_pcb Sheet: BACK-LAYER

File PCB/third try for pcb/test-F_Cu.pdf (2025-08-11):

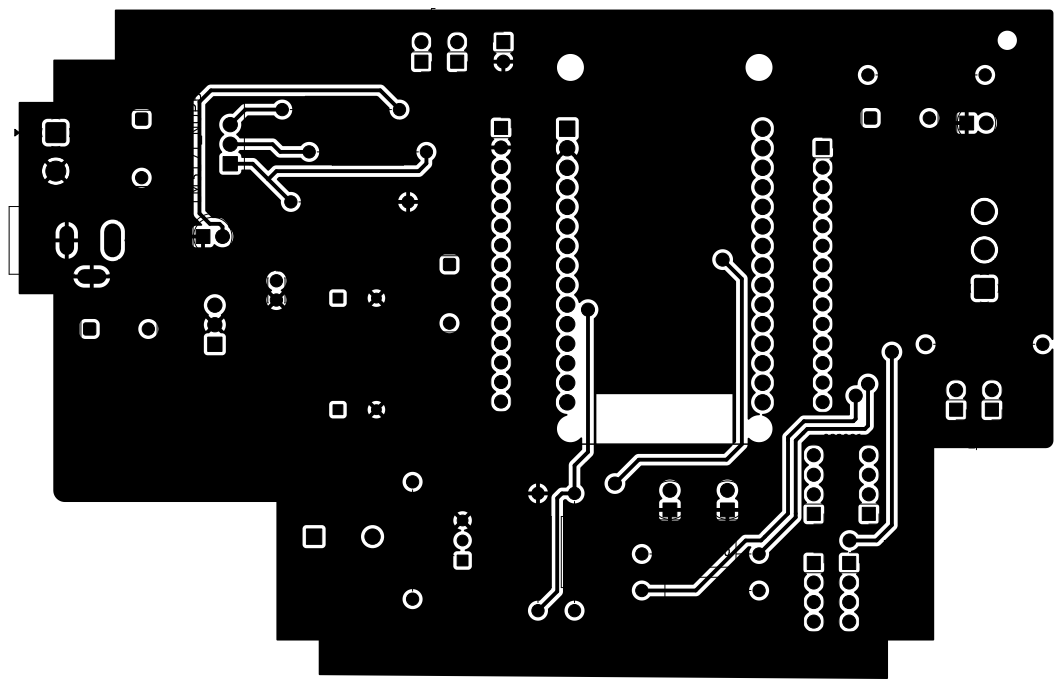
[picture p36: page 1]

Id: 1/9 Title: File: test.kicad_pcb Sheet: BACK-LAYER

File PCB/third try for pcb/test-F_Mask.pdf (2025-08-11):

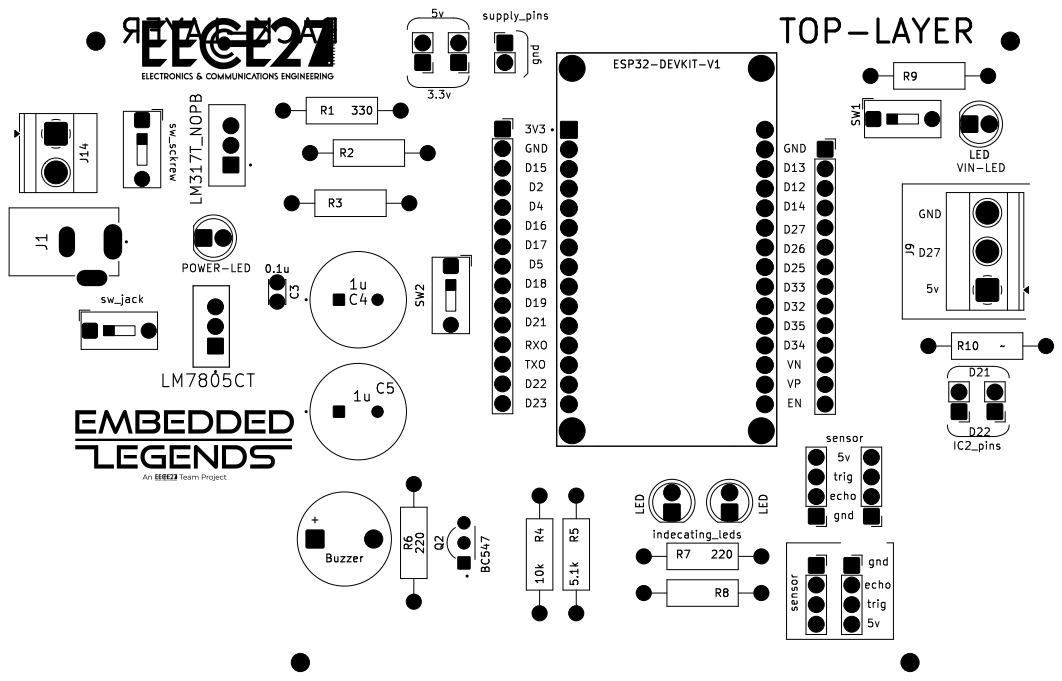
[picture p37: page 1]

Id: 7/9 Title: File: test.kicad_pcb Sheet: BACK-LAYER

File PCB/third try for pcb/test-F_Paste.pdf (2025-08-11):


Id: 3/9 Title: File: test.kicad_pcb Sheet: BACK-LAYER

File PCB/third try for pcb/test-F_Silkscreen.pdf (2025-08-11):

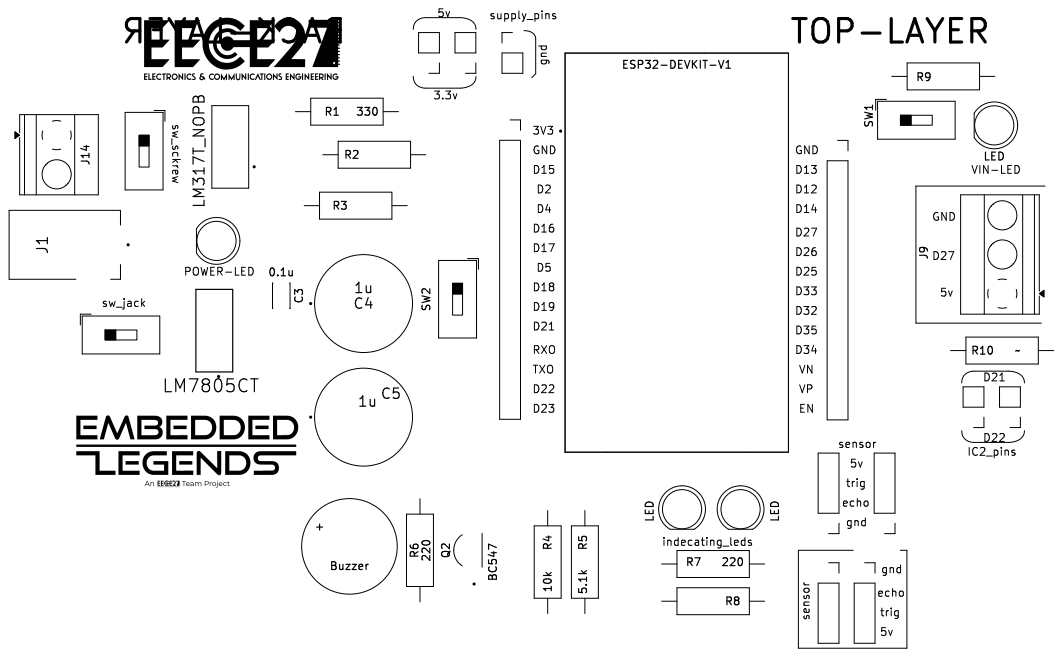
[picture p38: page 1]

Id: 5/9 Title: File: test.kicad_pcb Sheet:

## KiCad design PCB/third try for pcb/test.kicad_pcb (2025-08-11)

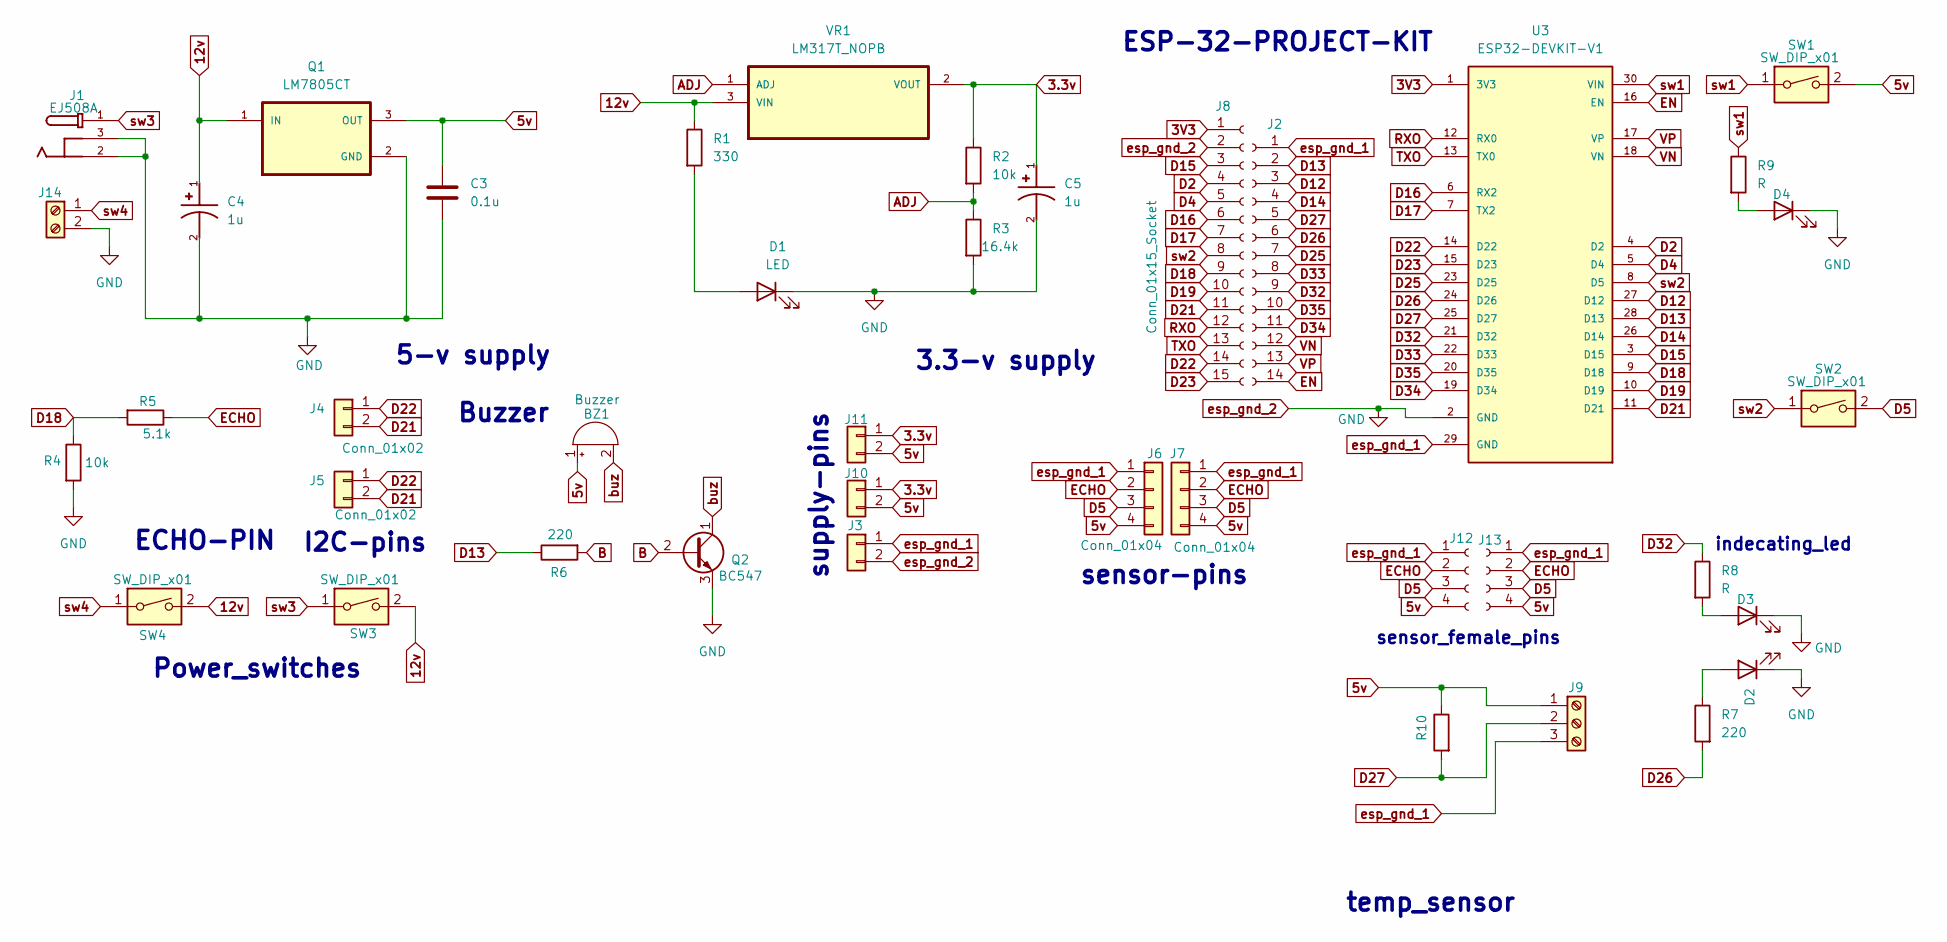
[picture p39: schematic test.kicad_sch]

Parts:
BZ1: Buzzer; Buzzer_12x9.5RM7.6
C3: 0.1u; C_Disc_D3.0mm_W2.0mm_P2.50mm
C4, C5: 1u; CAPPRD500W60D1330H2700; PARTREV Apr-20
D1, D2, D3, D4: LED; LED_D5.0mm
J1: EJ508A; MPD_EJ508A; PARTREV J
J2: Conn_01x14_Socket; PinSocket_1x14_P2.54mm_Vertical
J3, J4, J5, J10, J11: Conn_01x02; PinHeader_1x02_P2.54mm_Vertical
J6, J7: Conn_01x04; PinHeader_1x04_P2.54mm_Vertical
J8: Conn_01x15_Socket; PinSocket_1x15_P2.54mm_Vertical
J9: Screw_Terminal_01x03; TerminalBlock_Phoenix_MKDS-1,5-3_1x03_P5.00mm_Horizontal
J12, J13: Conn_01x04_Socket; PinSocket_1x04_P2.54mm_Vertical
J14: Screw_Terminal_01x02; TerminalBlock_Phoenix_MKDS-1,5-2_1x02_P5.00mm_Horizontal
Q1: LM7805CT; TO254P1054X470X2600-3; PARTREV LTR
Q2: BC547; TO92260P476H877-3
R1: 330; R_Axial_DIN0309_L9.0mm_D3.2mm_P15.24mm_Horizontal
R2, R4: 10k; R_Axial_DIN0309_L9.0mm_D3.2mm_P15.24mm_Horizontal
R3: 16.4k; R_Axial_DIN0309_L9.0mm_D3.2mm_P15.24mm_Horizontal
R5: 5.1k; R_Axial_DIN0309_L9.0mm_D3.2mm_P15.24mm_Horizontal
R6, R7: 220; R_Axial_DIN0309_L9.0mm_D3.2mm_P15.24mm_Horizontal
R8, R9: R; R_Axial_DIN0309_L9.0mm_D3.2mm_P15.24mm_Horizontal
R10: R_Axial_DIN0309_L9.0mm_D3.2mm_P15.24mm_Horizontal
SW1, SW2, SW3, SW4: SW_DIP_x01; SW_DIP_SPSTx01_Slide_9.78x4.72mm_W7.62mm_P2.54mm
U3: ESP32-DEVKIT-V1; MODULE_ESP32_DEVKIT_V1; PARTREV N/A
VR1: LM317T_NOPB; TO254P1054X470X1955-3

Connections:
3.3v: C5.1, J10.1, J11.1, R2.1, VR1.2 (VOUT)
3V3: J8.1, U3.1 (3V3)
5v: BZ1.1 (+), C3.1, J6.4, J7.4, J9.1, J10.2, J11.2, J12.4, J13.4, Q1.3 (OUT), R10.1, SW1.2
12v: C4.1, Q1.1 (IN), R1.1, SW3.2, SW4.2, VR1.3 (VIN)
ADJ: R2.2, R3.1, VR1.1 (ADJ)
B: Q2.2 (B), R6.2
D2: J8.4, U3.4 (D2)
D4: J8.5, U3.5 (D4)
D5: J6.3, J7.3, J12.3, J13.3, SW2.2
D12: J2.3, U3.27 (D12)
D13: J2.2, R6.1, U3.28 (D13)
D14: J2.4, U3.26 (D14)
D15: J8.3, U3.3 (D15)
D16: J8.6, U3.6 (RX2)
D17: J8.7, U3.7 (TX2)
D18: J8.9, R4.1, R5.2, U3.9 (D18)
D19: J8.10, U3.10 (D19)
D21: J4.2, J5.2, J8.11, U3.11 (D21)
D22: J4.1, J5.1, J8.14, U3.14 (D22)
D23: J8.15, U3.15 (D23)
D25: J2.7, U3.23 (D25)
D26: J2.6, R7.2, U3.24 (D26)
D27: J2.5, J9.2, R10.2, U3.25 (D27)
D32: J2.9, R8.1, U3.21 (D32)
D33: J2.8, U3.22 (D33)
D34: J2.11, U3.19 (D34)
D35: J2.10, U3.20 (D35)
ECHO: J6.2, J7.2, J12.2, J13.2, R5.1
EN: J2.14, U3.16 (EN)
unnamed: D1.2 (A), R1.2
unnamed: D2.2 (A), R7.1
unnamed: D3.2 (A), R8.2
unnamed: D4.2 (A), R9.2
RXO: J8.12, U3.12 (RX0)
TXO: J8.13, U3.13 (TX0)
VN: J2.12, U3.18 (VN)
VP: J2.13, U3.17 (VP)
buz: BZ1.2 (-), Q2.1 (C)
esp_gnd_1: J2.1, J3.1, J6.1, J7.1, J9.3, J12.1, J13.1, U3.29 (GND)
esp_gnd_2: C3.2, C4.2, C5.2, D1.1 (K), D2.1 (K), D3.1 (K), D4.1 (K), J1.2, J1.3, J3.2, J8.2, J14.2, Q1.2 (GND), Q2.3 (E), R3.2, R4.2, U3.2 (GND)
sw1: R9.1, SW1.1, U3.30 (VIN)
sw2: J8.8, SW2.1, U3.8 (D5)
sw3: J1.1, SW3.1
sw4: J14.1, SW4.1

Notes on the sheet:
supply-pins
Buzzer
ESP-32-PROJECT-KIT
ECHO-PIN
temp_sensor
3.3-v supply
sensor-pins
indecating_led
sensor_female_pins
5-v supply
Power_switches
I2C-pins

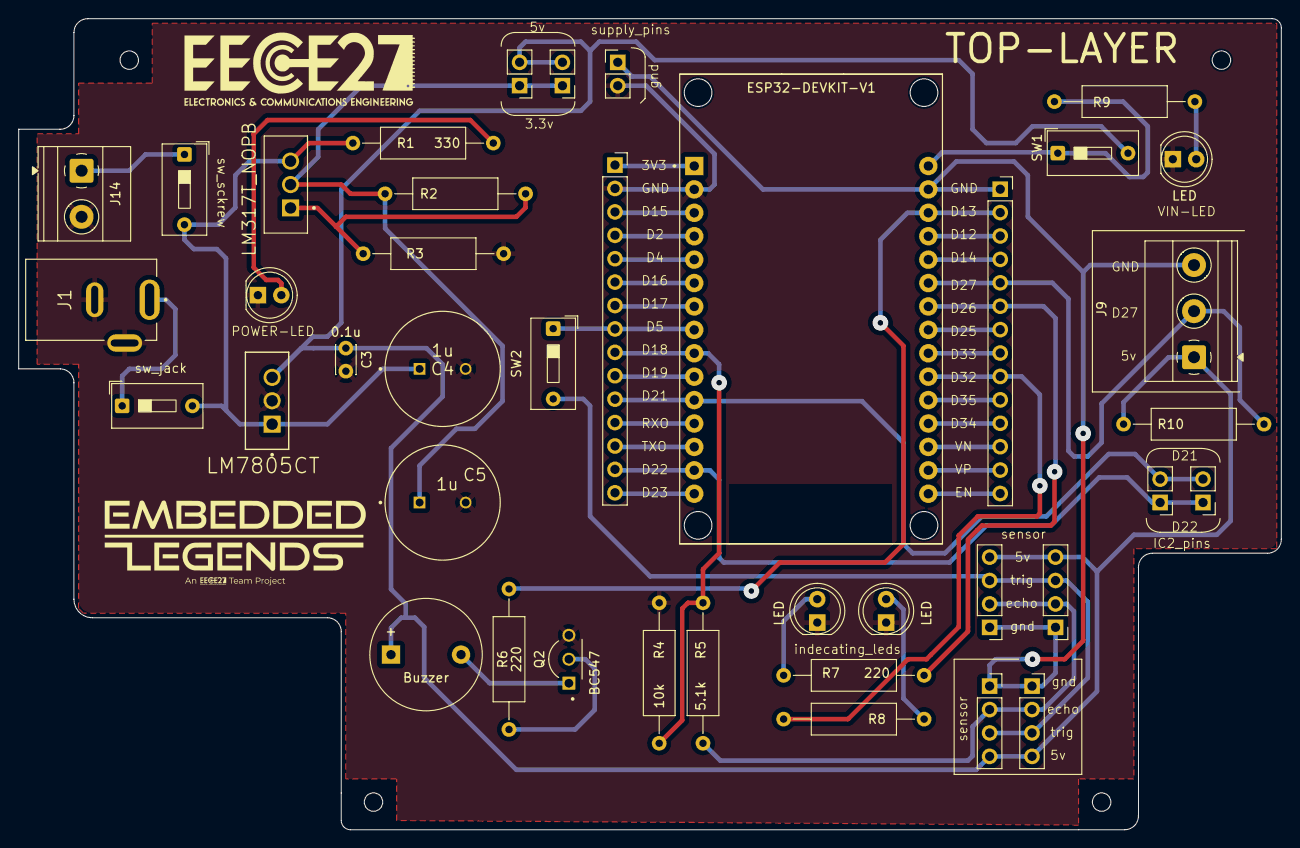
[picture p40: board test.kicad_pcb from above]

Board: 2 copper layers, 137.0 x 88.0 mm, 40 parts (0 on the bottom side), 44 nets.

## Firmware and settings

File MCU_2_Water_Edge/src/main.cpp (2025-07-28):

#include <Arduino.h>
#include "Water_Level/Water_Level.h"
#include "OLED/oled.h"
#include "Firebase_Sender.h"
#include "GSM/GSM.h"

// #define USE_FIREBASE
#define USE_FIREBASE

/* Global Variables *****************************************************************/

U8G2_SH1106_128X64_NONAME_1_HW_I2C u8g2(U8G2_R0, SCL, SDA, U8X8_PIN_NONE); // Oled Object

Data AllData;
// Struct to store all data initialization

Sensor_Type current_sensor = ToF; // Global Variable to quickly choose Depth Sensor
bool measureData = true;          // Flag to measure data

/***************************************************************************/

/* Menu Variables ***********************************************************/

const unsigned char *menu_icons[3] = {
    menu_icon_waterdrop,
    menu_icon_battery,
    menu_icon_temp};

const int n_items = 3;
char items[n_items][20] = {
    {"Water level 1"},
    {"Water level 2"},
    {"Temperature"}};

int previous;
int selected = 0;
int next;
int current_screen = 0;

// temp measurements
int temp_progress = 0; // temp_progress bar
float temp = 24;       // depth_1iable to increase the temp_progress bar(in cm)
char temp_buffer[10];  // temp_buffer to hold the converted number

// water level measurements
int progress = 0; // progress bar
char buffer[10];  // Buffer to hold the converted number
// water level_2 measurements
int progress2 = 0; // progress bar
char buffer2[10];  // Buffer to hold the converted number

/*************************************************************************/

void setup()
{
  Serial.begin(9600);
  /*Intializations*/
  if (measureData == true)
  {
    Sensor_init(current_sensor);
  }
  OLED_init();
  Water_Level_Debug_LED_Init(); // Initialize the Water Level Debug LED

  #ifdef USE_FIREBASE
  Setup_Firebase();
  #endif
  
  Setup_Coexistence();
  ESPNOW_Receiver_Init();

  #ifdef USE_GSM
  GSM_init();
  GSM_SMS_init();
  #endif

  /*Oled Config*/
  u8g2.setColorIndex(1); // white color
  u8g2.setBitmapMode(1);
  u8g2.begin();
}

void loop()
{
  // Get Sensor Data
  if (measureData == true)
  {
    AllData.water_level_2 = getDepth_Average_cm(current_sensor); // Measure Water Depth at Water Edge
  }

  /* Wait to Recieve ESP NOW Data *******************************************************************************/

  //! POLLING
  // Serial.println("Recieveing Data...");
  // while(isRecieved == false) {}
  // isRecieved = false;

  // Control Debug LED
  if (isRecieved == true)
  {
    digitalWrite(ESPNOW_DEBUG_LED, LOW);
    isRecieved = false;
  }

  /************************************************************************************************************/

  // Store Sensor Data in structure
  AllData.water_level_1 = receivedData.water_level_1;
  AllData.temp = receivedData.temp;

  // AllData.water_level_2 = getDepth_Average_cm(current_sensor); // Measure Water Depth at Water Edge

  /* Button Control ************************************************************************/
  if (current_screen == 0)
  {
    //* Up Button
    if (digitalRead(OLED_BUTTON_UP_PIN) == LOW) // Check if Button is pressed
    {
      delay(10);                                  // Debounce
      if (digitalRead(OLED_BUTTON_UP_PIN) == LOW) // Check if Button is still pressed
      {
        selected = selected - 1;
        if (selected < 0)
        {
          selected = n_items - 1;
        }
      }
      Serial.println("Up Button Pressed");
      while (digitalRead(OLED_BUTTON_UP_PIN) == LOW)
      {
        // Wait for Button Release
      }
    }

    //* Down Button
    if (digitalRead(OLED_BUTTON_DOWN_PIN) == LOW) // Check if Button is pressed
    {
      delay(10);                                    // Debounce
      if (digitalRead(OLED_BUTTON_DOWN_PIN) == LOW) // Check if Button is still pressed
      {
        selected = selected + 1;
        if (selected == n_items)
        {
          selected = 0;
        }
      }

      while (digitalRead(OLED_BUTTON_DOWN_PIN) == LOW)
      {
        // Wait for Button Release
      }
    }

    // Control Previous and Next
    previous = selected - 1;
    if (previous < 0)
    {
      previous = n_items - 1;
    }
    next = selected + 1;
    if (next >= n_items)
    {
      next = 0;
    }
  }

  //* Enter Button
  if ((digitalRead(OLED_BUTTON_SELECT_PIN) == LOW)) // Check if Button is pressed
  {
    delay(10);                                        // Debounce
    if ((digitalRead(OLED_BUTTON_SELECT_PIN) == LOW)) // Check if Button is still pressed
    {
      if (current_screen == 0)
      {
        current_screen = 1;
      }
      else if (current_screen == 1)
      {
        current_screen = 0;
      }
    }

    while (digitalRead(OLED_BUTTON_SELECT_PIN) == LOW)
    {
      // Wait for Button Release
    }
  }
  /* End of Buttons ****************************************************************************************/

  /* OLED Section *******************************************************************************/
  u8g2.setAutoPageClear(1);
  u8g2.firstPage();
  do
  {
    if (current_screen == 0)
    {
      // Menu Item 1
      u8g2.setFont(u8g_font_7x14);
      u8g2.drawStr(26, 15, items[0]);
      u8g2.drawXBMP(4, 2, 16, 16, menu_icons[0]);

      // Menu Item 2
      u8g2.setFont(u8g_font_7x14);
      u8g2.drawStr(26, 37, items[1]);
      u8g2.drawXBMP(4, 24, 16, 16, menu_icons[1]);

      // Menu Item 3
      u8g2.setFont(u8g_font_7x14);
      u8g2.drawStr(26, 59, items[2]);
      u8g2.drawXBMP(4, 46, 16, 16, menu_icons[2]);

      if (selected == 1)
      {
        u8g2.drawXBMP(0, 22, 128, 20, menu_sel_outline);
      }

      if (selected == 2)
      {
        u8g2.drawXBMP(0, 44, 128, 20, menu_sel_outline);
      }

      if (selected == 0)
      {
        u8g2.drawXBMP(0, 0, 128, 20, menu_sel_outline);
      }

      u8g2.drawXBMP(120, 0, 8, 64, menu_scrollbar_bckg);

      // draw scrollbar handle
      u8g2.drawBox(125, 64 / n_items * selected + 6, 3, 8);
    }

    else if (current_screen == 1 && selected == 2)
    {
      u8g2.setFont(u8g2_font_helvB08_tr);       // font
      dtostrf(AllData.temp, 6, 2, temp_buffer); // Width = 6, Precision = 2 decimal places

      u8g2.setColorIndex(1); // white color
      u8g2.drawXBMP(0, 0, 128, 64, temp_measurement);

      u8g2.drawStr(25, 55, temp_buffer);

      u8g2.setColorIndex(0);
      u8g2.drawBox(2, 15, 124, 8);
      u8g2.setColorIndex(1);
      u8g2.drawBox(2, 16, temp_progress, 6);
    }
    else if (current_screen == 1 and selected == 0)
    {
      u8g2.setFont(u8g2_font_helvB08_tr);           // font
      dtostrf(AllData.water_level_1, 6, 2, buffer); // Width = 6, Precision = 2 decimal places
      u8g2.setColorIndex(1);                        // white color
      u8g2.drawXBMP(0, 0, 128, 64, waterlevel_measurement);

      u8g2.drawStr(25, 55, buffer);

      u8g2.setColorIndex(0);
      u8g2.drawBox(2, 15, 124, 8);
      u8g2.setColorIndex(1);
      u8g2.drawBox(2, 16, progress, 6);
    }
    else if (current_screen == 1 and selected == 1)
    {
      u8g2.setFont(u8g2_font_helvB08_tr);            // font
      dtostrf(AllData.water_level_2, 6, 2, buffer2); // Width = 6, Precision = 2 decimal places
      u8g2.setColorIndex(1);                         // white color
      u8g2.drawXBMP(0, 0, 128, 64, waterlevel_measurement);

      u8g2.drawStr(25, 55, buffer2);

      u8g2.setColorIndex(0);
      u8g2.drawBox(2, 15, 124, 8);
      u8g2.setColorIndex(1);
      u8g2.drawBox(2, 16, progress2, 6);
    }

  } while (u8g2.nextPage());
  u8g2.setAutoPageClear(0);

  /* End of OLED Control********************************************************************************************/

  /* Variables Control ***************************************************************************************/
  // temp += 0.05; //? Change
  // if(temp > 40)
  // {
  //   temp = 24; //? Change
  // }
  if ((temp_progress < 124) && (AllData.temp < 40))
  {
    temp_progress = (AllData.temp * 124) / 40;
  }
  else
  {
    temp_progress = 0;
  }

  // depth_1 +=0.05; //? Change
  // if(depth_1 > 20)
  // {
  //   depth_1 = 5.5; //? Change
  // }
  if (progress < 124 && AllData.water_level_1 < 28)
  {
    progress = (AllData.water_level_1 * 124) / 28;
  }
  else
  {
    // progress = 0;
  }

  if (progress2 < 124 && AllData.water_level_2 < 28)
  {
    progress2 = (AllData.water_level_2 * 124) / 28;
  }
  else
  {
    // progress2 = 0;
  }

  /* End of Variables Control ***************************************************************************************/

  /* Send Data to web server **********************************************************************/

  if (isRecieved == true)
  {
    Water_Level_Debug_LED_On(); // Turn on the Debug LED when data is received
    delay(10);
    Water_Level_Debug_LED_Off(); // Turn off the Debug LED after a short delay
    // ESPNOW_Receiver_deInit();                                                             // Deinitialize ESP-NOW before sending data to Firebase
    #ifdef USE_FIREBASE
    Send_Firebase_Data(AllData.water_level_1, AllData.temp, AllData.water_level_2, -200); // Send data to Firebase
    #endif

    #ifdef USE_GSM
    GSM_sendData(AllData.water_level_1, AllData.temp, AllData.water_level_2);             // Send data via GSM
    #endif
    // ESPNOW_Receiver_Init();                                                               // Reinitialize ESP-NOW after sending data
    isRecieved = false;   
                                                                    // Reset the flag after sending data
  }
}

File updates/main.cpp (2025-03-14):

#include <Arduino.h>
#include "Water_Level/Water_Level.h"
#include "ESPNOW_Reciever/Reciever.h"
#include "OLED/oled.h"
#include "Firebase_Sender.h"
#include "esp_wifi.h"
#include <WiFi.h>
#include "U8g2lib.h"  // OLED library

// OLED Display Initialization
U8G2_SSD1306_128X64_NONAME_F_HW_I2C u8g2(U8G2_R0, SCL, SDA, U8X8_PIN_NONE);

/* Structure to store combined sensor data */
struct Data : public SensorData {
  float32 water_level_2;
} AllData;

/* External variable from Reciever.cpp */
extern SensorData receivedData;

/* Menu Variables */
const unsigned char* menu_icons[3] = {
  menu_icon_waterdrop,
  menu_icon_battery,
  menu_icon_temp
};

const int n_items = 3;
char items[n_items][20] = {
  {"Water level"},
  {"Battery level"},
  {"Temperature"}
};

int previous;
int selected = 0;
int next;
int current_screen = 0;

/* Temperature measurements */
int temp_progress = 0;
float temp = 24;
char temp_buffer[10];

/* Water level measurements */
int progress = 0;
float depth_1 = 0;
char buffer[10];

void setup() {
  /* Initializations */
  Sensor_init(HCSR04);
  OLED_init();
  Setup_Firebase();           // 🔹 **Initialize Firebase**
  ESPNOW_Receiver_Init();     // 🔹 **Initialize ESP-NOW reception (WiFi STA mode)**
  Serial.begin(9600);

  /* OLED Configuration */
  u8g2.setColorIndex(1);   // White color
  u8g2.setBitmapMode(1);
  u8g2.begin();
}

void loop() {
  Serial.println("Waiting for ESP-NOW data...");
  while (!isReceived) {}  // 🔹 **Wait for ESP-NOW data before switching to WiFi**
  isReceived = false;

  /* Store received data from ESP-NOW */
  AllData.water_level_1 = receivedData.water_level_1;
  AllData.temp = receivedData.temp;
  depth_1 = AllData.water_level_1;

  Serial.printf("Received: Water Level 1 = %.2f, Temperature = %.2f\n", AllData.water_level_1, AllData.temp);

  /* Menu Navigation - Button Control (Original Logic) */
  if (current_screen == 0) {
    // Up Button
    if (digitalRead(OLED_BUTTON_UP_PIN) == LOW) {
      delay(200);
      selected = selected - 1;
      if (selected < 0) {
        selected = n_items - 1;
      }
    }

    // Down Button
    if (digitalRead(OLED_BUTTON_DOWN_PIN) == LOW) {
      delay(200);
      selected = selected + 1;
      if (selected == n_items) {
        selected = 0;
      }
    }

    previous = selected - 1;
    if (previous < 0) {
      previous = n_items - 1;
    }
    next = selected + 1;
    if (next >= n_items) {
      next = 0;
    }
  }

  // Select Button toggles between menu and detailed display
  if (digitalRead(OLED_BUTTON_SELECT_PIN) == LOW) {
    delay(200);
    current_screen = !current_screen;
  }

  /* OLED Display Update */
  u8g2.firstPage();
  do {
    if (current_screen == 0) {
      // Menu display
      u8g2.setFont(u8g_font_7x14);
      u8g2.drawStr(26, 15, items[0]);
      u8g2.drawXBMP(4, 2, 16, 16, menu_icons[0]);

      u8g2.setFont(u8g_font_7x14);
      u8g2.drawStr(26, 37, items[1]);
      u8g2.drawXBMP(4, 24, 16, 16, menu_icons[1]);

      u8g2.setFont(u8g_font_7x14);
      u8g2.drawStr(26, 59, items[2]);
      u8g2.drawXBMP(4, 46, 16, 16, menu_icons[2]);

      if (selected == 0)
        u8g2.drawXBMP(0, 0, 128, 20, menu_sel_outline);
      else if (selected == 1)
        u8g2.drawXBMP(0, 22, 128, 20, menu_sel_outline);
      else if (selected == 2)
        u8g2.drawXBMP(0, 44, 128, 20, menu_sel_outline);

      u8g2.drawXBMP(120, 0, 8, 64, menu_scrollbar_bckg);
      u8g2.drawBox(125, 64 / n_items * selected + 6, 3, 8);
    } else {
      // Detailed display based on selected menu item
      u8g2.setFont(u8g2_font_helvB08_tr);
      if (selected == 0) { // Water Level detail
        dtostrf(depth_1, 6, 2, buffer);
        u8g2.drawXBMP(0, 0, 128, 64, waterlevel_measurement);
        u8g2.drawStr(25, 55, buffer);
        u8g2.drawBox(2, 16, progress, 6);
      } else if (selected == 2) { // Temperature detail
        dtostrf(temp, 6, 2, temp_buffer);
        u8g2.drawXBMP(0, 0, 128, 64, temp_measurement);
        u8g2.drawStr(25, 55, temp_buffer);
        u8g2.drawBox(2, 16, temp_progress, 6);
      }
    }
  } while (u8g2.nextPage());

  /* Update Progress Bars */
  if ((temp_progress < 124) && (depth_1 < 40))
    temp_progress = (depth_1 * 124) / 40;
  else
    temp_progress = 0;

  depth_1 += 0.05;
  if (depth_1 > 20)
    depth_1 = 5.5;

  if (progress < 124 && depth_1 < 20)
    progress = (depth_1 * 124) / 20;
  else
    progress = 0;

  /* 🔹 Enable WiFi and send data to Firebase */
  Enable_WiFi();
  Send_Firebase_Data(AllData.water_level_1, AllData.temp);

  /* 🔹 Switch back to ESP-NOW mode (Disconnect WiFi from router) */
  Enable_ESPNow();
}

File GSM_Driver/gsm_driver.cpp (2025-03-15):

/*
 * gsm_driver.cpp
 *
 *  Created on: Mar 1, 2025
 *      Author: Ziad Mostafa (Embedded Legeneds member)
 *
 *  This file implements GSM management functions for the SIM800L module using TinyGSM.
 */

#include "gsm_driver.h"

// Using ESP32 HardwareSerial on UART2
HardwareSerial SerialGSM(2);
TinyGsm modem(SerialGSM);
TinyGsmClient gsm_client(modem);

/*
 * Initializes the SIM800L module and connects to the network.
 */
void gsm_init(void)
{
    SerialGSM.begin(9600, SERIAL_8N1, RXD2, TXD2);
    Serial.println("Initializing GSM...");

    // Power on the SIM800L module
    modem.sendAT("+CFUN=1");
    delay(1000);

    if (!modem.restart()) {
        Serial.println("Failed to restart GSM module!");
        return;
    }

    Serial.println("Modem restarted. Checking network...");

    // Check if SIM card is inserted
    if (modem.getSimStatus() != 3) {
        Serial.println("SIM card not detected!");
        return;
    }

    // Connect to the GSM network
    if (!gsm_isConnected()) {
        Serial.println("Failed to connect to network.");
        return;
    }

    // Enable GPRS for HTTP requests
    if (!gsm_enableGPRS()) {
        Serial.println("Failed to enable GPRS.");
        return;
    }

    Serial.println("GSM module is ready.");
}

/*
 * Checks if the SIM800L is connected to a mobile network.
 */
bool gsm_isConnected(void)
{
    Serial.println("Checking network connection...");
    if (!modem.waitForNetwork(60000)) { // Wait up to 60 seconds
        Serial.println("Network unavailable!");
        return false;
    }
    Serial.println("Network connected.");
    return true;
}

/*
 * Enables GPRS for data transfer.
 */
bool gsm_enableGPRS(void)
{
    Serial.println("Enabling GPRS...");
    
    if (modem.isGprsConnected()) {
        Serial.println("GPRS already enabled.");
        return true;
    }

    // Try to connect with APN (Modify APN credentials if required)
    for (int i = 0; i < 3; i++) {
        if (modem.gprsConnect(APN, "", "")) {
            Serial.println("GPRS connected.");
            return true;
        }
        Serial.println("Retrying GPRS connection...");
        delay(3000);
    }

    Serial.println("GPRS connection failed!");
    return false;
}

/*
 * Disables GPRS to save power.
 */
void gsm_disableGPRS(void)
{
    Serial.println("Disabling GPRS...");
    modem.gprsDisconnect();
    Serial.println("GPRS disconnected.");
}

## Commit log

2025-02-28 ESPNOW Sender and Receiver codes
    these are the code I have written until now for the Communication between Two esp32
2025-02-28 Temp sensor
2025-03-05 SIM800L Driver
    this is the driver of GSM for SIM800L , but still have a problem of HTTPS connection
    [gsm_driver.cpp]
2025-03-05 Firebase module using GSM
    this is the firebase module driver using GSM
2025-03-13 Temprature Sensor done
2025-03-13 these are the updates for files for solving espnow and firebase connection problem
    [Firebase_Sender.cpp, Reciever.cpp, main.cpp]
2025-03-16 Added Push Button Debounce MCU2
2025-03-16 Changed Used sensor in MCU2 to ToF
2025-03-16 Data Reception LED Configured
2025-03-18 Firebase stuff (Failed Test)
    [Firebase_Sender.cpp, Reciever.cpp, main.cpp]
2025-03-19 Current Sensor Var for MCu1
2025-04-14 Set Current sensor variable to tof
2025-04-14 changed sensor to HCSR04
2025-04-14 Changed MCU2 sensor to ToF
2025-04-14 solve the problem of disapearing the diplayed digits of water level 2
    بارك الله فيما رزق
    [main.cpp]
2025-04-17 pin changes mcu 1 pcb
2025-04-17 adding interrupt feature
2025-04-18 Problem figured out and fixed
    [Reciever.cpp, Sender.cpp, main.cpp]
2025-05-08 fixed GSM format and added options for data upload
    [Firebase_Sender.cpp, GSM.cpp, main.cpp]
2025-06-15 adjusted GSM uart pins
2025-06-17 added debug LED and fixed some gsm stuff
    [GSM.cpp, Reciever.cpp, Water_Level.cpp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]
2025-07-23 Added finiished research
    We updated it by adding the PCB prototype
2025-08-09 finished AI Prototype
    It works as an AI Prototype back end
2025-08-10 ESP initialized
    Now we can access the ESP32
2025-08-10 Added Reading variables
    now we can read the variables from the ESP32
2025-08-10 Added AI Prototype
    It works well
2025-08-11 Added PCB
    now we can view it
    [test-B_Cu.gbr, test-B_Mask.gbr, test-B_Paste.gbr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]
